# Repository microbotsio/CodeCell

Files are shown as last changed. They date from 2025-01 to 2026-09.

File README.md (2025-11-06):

# CodeCell

CodeCell

## Overview

CodeCell is a family of tiny boards that help you miniaturize your DIY robots, wearables, and IoT projects with ease! Designed for makers, each CodeCell features an Arduino-compatible ESP32 microcontroller, onboard sensors, and smart power management - all programmable over a standard USB-C cable. The USB-C port also charges the LiPo battery that connects directly to the onboard connector.

All CodeCell modules are supported by the **CodeCell Arduino Library**, which provides simple, ready-to-use functions for light, proximity, motion, and power management.  

You can even connect your CodeCell to our companion **MicroLink App** to add wireless sliders, buttons, joysticks, real-time sensor data, and a live 20-character display - Perfect for debugging!

Each version of CodeCell shares the same compact 1.85 cm (C3/C6) or 2.25 cm (C6 Drive) form factor and includes:

- **USB-C Port** – for programming, serial communication, and battery charging.  
- **LiPo Connector** – works with the included cable and the optional 170 mAh 20C battery (1.25 mm pitch).  
- **BQ24232 Power Management** – enables dynamic power-path control for simultaneous operation and charging.  
- **Programmable GPIO/PWM/ADC/I2C Pins** – expand your project with additional sensors, displays, or actuators.
- **CodeCell Library Support** – easy Arduino functions for reading sensors, LEDs, PWM, and sleep triggers.  
- **MicroLink App Integration** – wireless control and real-time feedback from your phone.
- **Sensors** – includes a **VCNL4040 light/proximity sensor** and the C3/C6/C6-Drive also include a **BNO085 9-axis IMU motion sensor** with onboard sensor-fusion algorithms for advanced orientation, motion, and activity detection.  

Available Versions:

| Model | Microcontroller | Features | Typical Use |
|:---|:---|:---|:---|
| **CodeCell C3 Light** | ESP32-C3-MINI-1-N4 | 4MB Flash, Wi-Fi 4 + BLE 5, LiPo Charging via USB-C, Light + Proximity Sensor | Basic sensing and IoT projects |
| **CodeCell C3** | ESP32-C3-MINI-1-N4 | 4MB Flash, Wi-Fi 4 + BLE 5, LiPo Charging via USB-C, Light + Proximity Sensor + 9-Axis IMU Motion Sensor | Robotics & Wearables |
| **CodeCell C6** | ESP32-C6-MINI-1-H8 | 8MB Flash, Wi-Fi 6 + BLE 5 + Zigbee, LiPo Charging via USB-C, Light + Proximity + 9-Axis IMU Sensor | Robotics & Wearables with Low-Power Modes |
| **CodeCell C6 Drive** | ESP32-C6-MINI-1-H8 | 8MB Flash, Wi-Fi 6 + BLE 5 + Zigbee, LiPo Charging via USB-C, Light + Proximity + 9-Axis IMU Sensor, Dual H-Bridge Motor Drivers | All-in-One Robotics Controller |

### 📦 Included in Every Box
- CodeCell module (C3 Light / C3 / C6 / C6 Drive)  
- Four M1.2 screws  
- Female headers (optional soldering)  
- 1.25 mm battery cable  
- Optional 170 mAh LiPo battery (add-on)

---

## Getting Started with the CodeCell Library

Get started and explore tutorials [here](https://microbots.io/pages/learn-codecell).

### 🧰 Arduino IDE Setup

Make sure the ESP32 boards package is installed  
(*Boards Manager → search for "esp32" by Espressif*).

#### For CodeCell C3 (ESP32-C3)
- Board: ESP32C3 Dev Module  
- USB CDC On Boot: Enabled        // Required for Serial over USB  
- CPU Frequency: 160 MHz  
- Flash Size: 4 MB (32 Mb)  
- Partition Scheme: Minimal SPIFFS (1.9MB APP with OTA / 190KB SPIFFS)  
- Port: Select the COM port for your CodeCell C3

#### For CodeCell C6 (ESP32-C6)
- Board: ESP32C6 Dev Module  
- USB CDC On Boot: Enabled        // Required for Serial over USB  
- CPU Frequency: 160 MHz  
- Flash Size: 8 MB (64 Mb)  
- Partition Scheme: 8M with SPIFFS (3 MB APP / 1.5 MB SPIFFS)  
- Port: Select the COM port for your CodeCell C6

### ⚙️ Init()

To initialize the CodeCell, use the `myCodeCell.Init()` function with one or more predefined macros.  
Each macro corresponds to a specific sensing function.

#### Available Macros
- LIGHT                          // Light + proximity sensing  
- MOTION_ACCELEROMETER           // 3-axis acceleration  
- MOTION_GYRO                    // 3-axis angular velocity  
- MOTION_MAGNETOMETER            // 3-axis magnetic field  
- MOTION_LINEAR_ACC              // Linear acceleration  
- MOTION_GRAVITY                 // Gravity vector  
- MOTION_ROTATION                // Roll, pitch, yaw (with mag)  
- MOTION_ROTATION_NO_MAG         // Roll, pitch, yaw (no mag)  
- MOTION_STEP_COUNTER            // Step count  
- MOTION_STATE                   // On table / Stationary / Stable / In motion  
- MOTION_TAP_DETECTOR            // Tap detection  
- MOTION_ACTIVITY                // Activity classification  

#### Example Usage
- myCodeCell.Init(LIGHT);                                 // Light only  
- myCodeCell.Init(LIGHT + MOTION_ROTATION);               // Light + orientation  
- myCodeCell.Init(LIGHT + MOTION_ROTATION + MOTION_STATE);// Light + orientation + state  

🧠 Combine multiple macros using the `+` operator to enable multiple sensors.

### 🔁 Run()

The `myCodeCell.Run()` function reads sensor data at a defined frequency and manages power and LED status.

#### Example
if (myCodeCell.Run(10)) {
  // Executes code every 10 Hz (every 100 ms)
}

- `myCodeCell.Run(10)` → returns `true` at 10 Hz (every 100 ms)  
- Read all enabled sensors at this rate  (Range: 1Hz - 100Hz)
- Also handles the LED power indicator and power status 

**Low battery behavior:**  
- Below ~3.3 V → LED blinks red ×10 → enters sleep until USB is reconnected  
- On USB → continues running loop(); LED shows charging/charged status  

### 🔋 Power & Battery Functions

#### PowerStateRead()
uint8_t state = myCodeCell.PowerStateRead();

Return values:
- 0 = Running from LiPo Battery  
- 1 = Running from USB Power  
- 2 = Power Initializing  
- 3 = Battery Low  
- 4 = Battery Fully Charged  
- 5 = Battery Charging  

#### BatteryVoltageRead()
int mv = myCodeCell.BatteryVoltageRead();   // e.g. 3720 (mV)  
Returns the LiPo voltage in millivolts — great for thresholds or logging.

#### BatteryLevelRead()
uint16_t lvl = myCodeCell.BatteryLevelRead();

Return values:
- 1–100  = Approximate battery percentage  
- 101    = Charging (USB connected, charging)  
- 102    = USB Power (bypassing battery)  

Example:
if (lvl <= 100) { Serial.println("Battery: " + String(lvl) + "%"); }  
else if (lvl == 101) { Serial.println("Charging..."); }  
else if (lvl == 102) { Serial.println("USB Power"); }  

### 📈 Reading Sensors

After initialization, you can read the sensors using these functions:

- Light_ProximityRead()                                           // Proximity  
- Light_WhiteRead()                                               // White light intensity  
- Light_AmbientRead()                                             // Ambient light  
- Motion_TapRead()                                                // Tap detection (1 = tap, 0 = none)  
- Motion_StepCounterRead()                                        // Step count  
- Motion_StateRead()                                              // On Table=1, Stationary=2, Stable=3, Motion=4  
- Motion_ActivityRead()                                           // Driving=1, Cycling=2, Walking=3/6, Still=4, Tilting=5, Running=7, Climbing=8  
- Motion_AccelerometerRead(float &x, float &y, float &z)          // Accelerometer (m/s²)  
- Motion_GyroRead(float &x, float &y, float &z)                   // Gyroscope (°/s)  
- Motion_MagnetometerRead(float &x, float &y, float &z)           // Magnetometer (µT)  
- Motion_GravityRead(float &x, float &y, float &z)                // Gravity vector  
- Motion_LinearAccRead(float &x, float &y, float &z)              // Linear acceleration  
- Motion_RotationRead(float &roll, float &pitch, float &yaw)      // Rotation (degrees)  
- Motion_RotationNoMagRead(float &roll, float &pitch, float &yaw) // Rotation w/o mag  
- Motion_RotationVectorRead(float &vec_r, float &vec_i, float &vec_j, float &vec_k) // Quaternion  

#### Example Usage
- uint16_t proximity = myCodeCell.Light_ProximityRead();  
- myCodeCell.Motion_AccelerometerRead(x, y, z);  
- myCodeCell.Motion_RotationRead(roll, pitch, yaw);  

🧠 Tip: Use `myCodeCell.PrintSensors();` to print all enabled sensor readings to the Serial Monitor.

### ⚡ GPIO Control
- myCodeCell.pinWrite(uint8_t pin, bool value);              // Digital write  
- myCodeCell.pinRead(uint8_t pin);                           // Digital read  
- myCodeCell.pinPWM(uint8_t pin, uint16_t freq, uint8_t dc); // PWM output (Hz, duty%)  
- myCodeCell.pinADC(uint8_t pin);                            // Analog read  

### 💡 Onboard LED Control
- myCodeCell.LED_SetBrightness(0);   // Turn off CodeCell LED  
- myCodeCell.LED_SetBrightness(10);  // Full brightness  

### 💤 Sleep Functions
- myCodeCell.SleepTimer(uint16_t sleep_sec);  
- myCodeCell.SleepProximityTrigger(uint16_t threshold);  // C6 only  
- myCodeCell.SleepLightTrigger(uint16_t threshold);      // C6 only  
- myCodeCell.SleepDarkTrigger(uint16_t threshold);       // C6 only  
- myCodeCell.SleepTapTrigger();                          // C6 only  

### 📱 MicroLink App Integration
- Download the MicroLink library to connect the CodeCell with the companion smartphone app.  
- Enables wireless sensor reading, joystick control, buttons and sliders.  

---

## Attribution
This 'CodeCell' library contains various features, including device intialization, power managment, light sensning and motion sensing. The VCNL4040 light sensor code does not rely on any external libraries. But some of the BNO085 Motion-sensor functions were adapted from the [SparkFun BNO08x Arduino Library](https://github.com/sparkfun/SparkFun_BNO08x_Arduino_Library) and the official library provided by [CEVA](https://github.com/ceva-dsp/sh2/tree/main) for the SH2 sensor hub.

The SparkFun BNO08x library, originally written by Nathan Seidle and adjusted by Pete Lewis at SparkFun Electronics, is released under the MIT License. Significant modifications were made to adapt it and integrate into the 'CodeCell' library.

Additionally, this project incorporates the official [CEVA SH2 sensor hub library files](https://github.com/ceva-dsp/sh2/tree/main), which is licensed under the [Apache License 2.0](http://www.apache.org/licenses/LICENSE-2.0).

CEVA’s notice is as follows:

This software is licensed from CEVA, Inc.  
Copyright (c) CEVA, Inc. and its licensors. All rights reserved.  
CEVA and the CEVA logo are trademarks of CEVA, Inc.  
For more information, visit [CEVA's website](https://www.ceva-dsp.com/app/motion-sensing/).

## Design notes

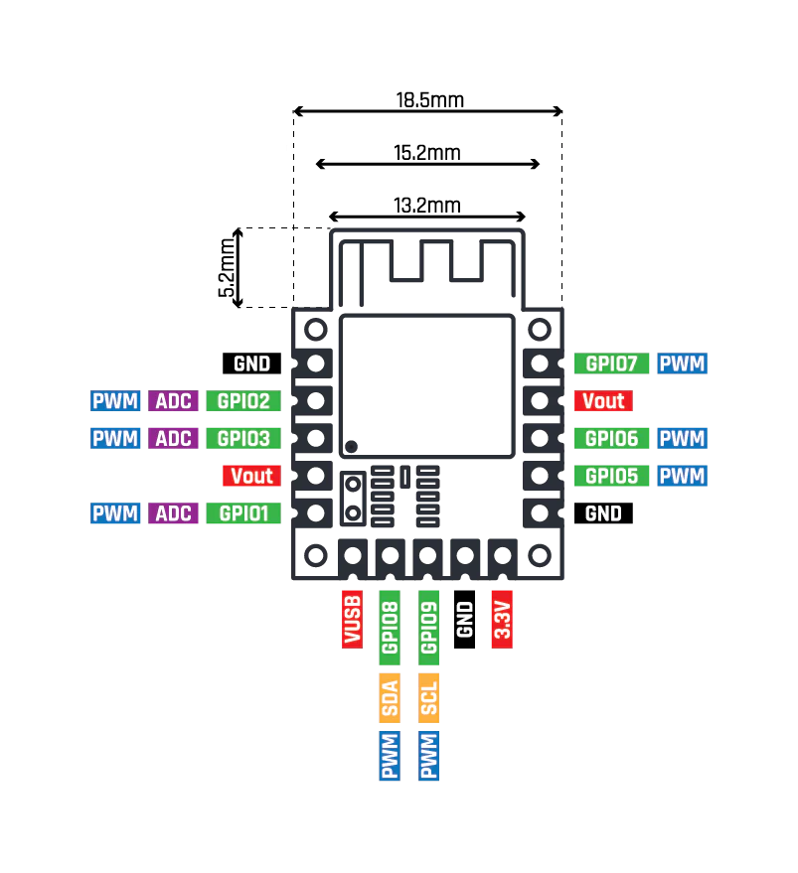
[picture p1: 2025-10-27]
hardware/CodeCell C3 Light/CodeCell C3 Light Pin Map.png

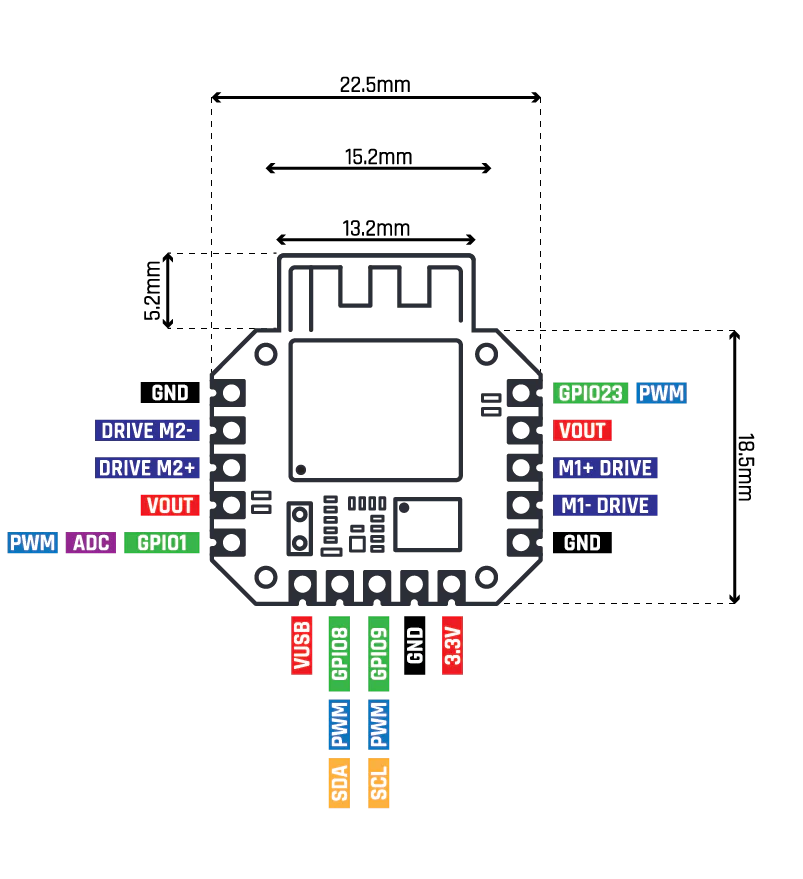
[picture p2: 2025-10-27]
hardware/CodeCell C6 Drive/CodeCell C6 Drive Pin Map.png

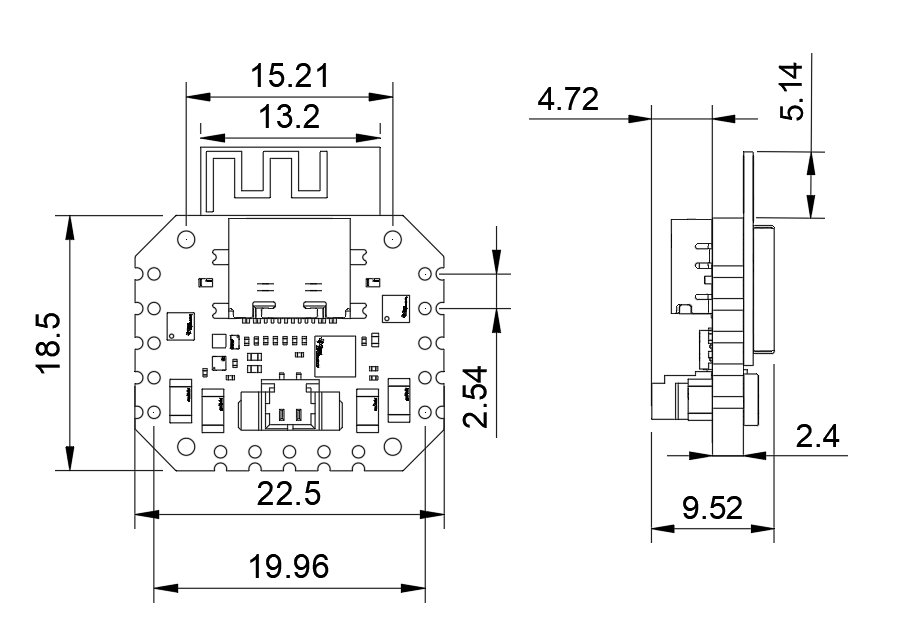
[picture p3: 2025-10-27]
hardware/CodeCell C6 Drive/CodeCell C6 Drive Drawing.png

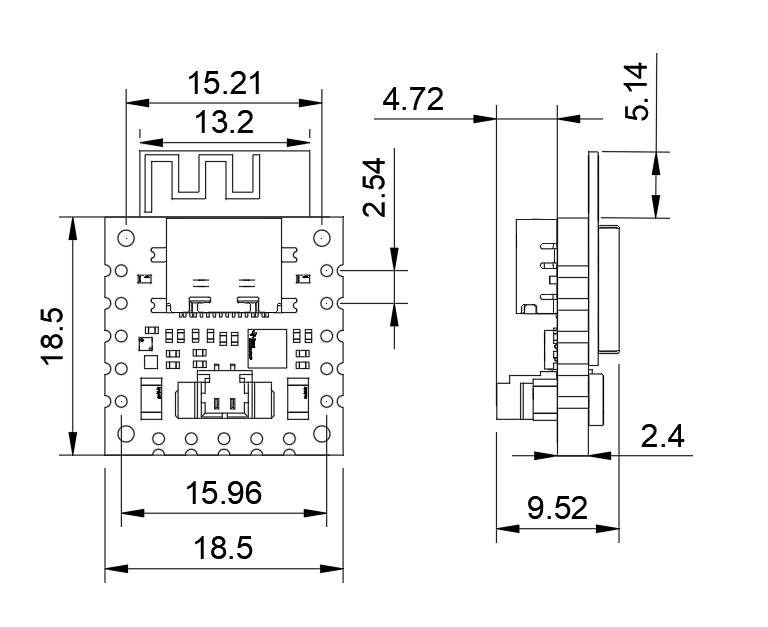
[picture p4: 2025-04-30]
hardware/CodeCell C3/codecell drawing.png

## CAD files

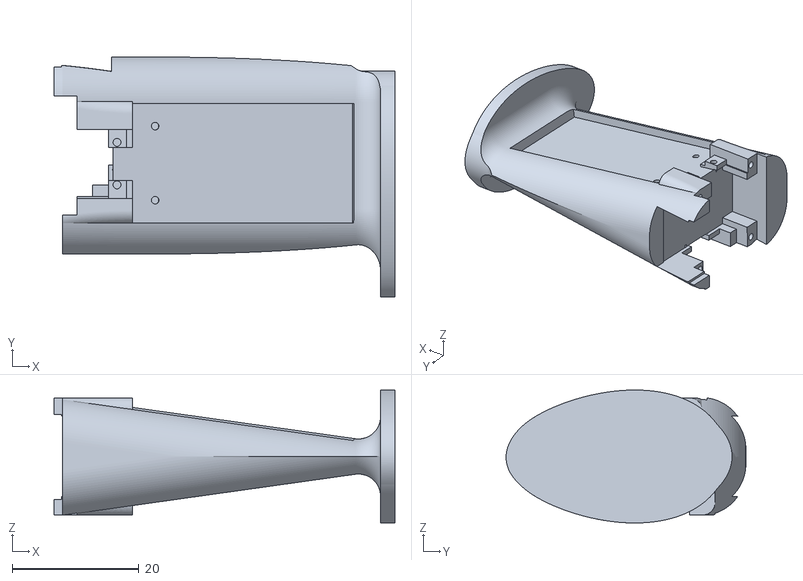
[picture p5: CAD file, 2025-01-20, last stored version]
hardware/Projects/Flappy Bot/FlappyBot_Holder.stl
53.9 x 37.9 x 21.0

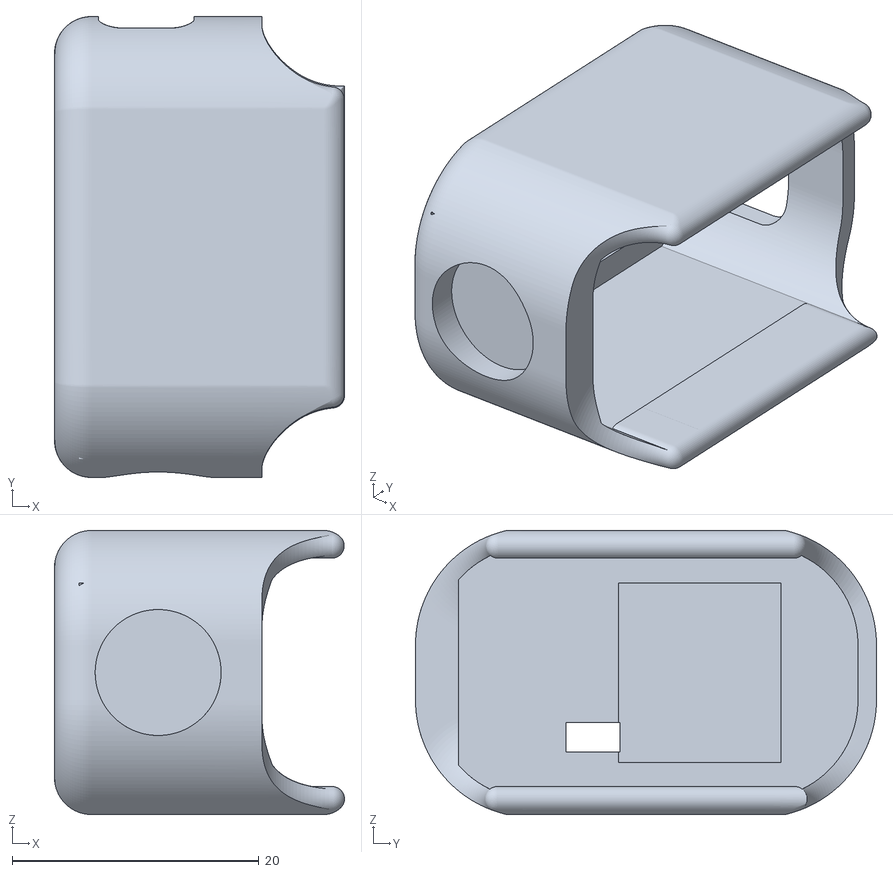
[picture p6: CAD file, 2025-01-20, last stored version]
hardware/Projects/Flappy Bot/FlappyBot_Head.stl
23.5 x 37.3 x 23.0

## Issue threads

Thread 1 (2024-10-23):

Sensor init issue

quinm0, 2024-10-23:
Hi, I plan on looking into this more myself but I just want to document the first issue I got

I was using the example from the library

```
#include <CodeCell.h>

CodeCell myCodeCell;

/*
 * Overview:
 * This code shows you how easy it is to set up and run the CodeCell. You just needs to specify which sensors to enable by
 * passing the appropriate macros to the `Init()` function and use the `Run()` function to handle the power and battery management.
 *
 **** Initialization (`Init` function):
 *
 * To initialize the CodeCell, use the `myCodeCell.Init()` function with one or more of the predefined macros. Each macro
 * corresponds to a specific sensing function. Here are the available macros:
 *
 * - `LIGHT`                          // Enables Light Sensing
 * - `MOTION_ACCELEROMETER`           // Enables Accelerometer Sensing
 * - `MOTION_GYRO`                    // Enables Gyroscope Sensing
 * - `MOTION_MAGNETOMETER`            // Enables Magnetometer Sensing
 * - `MOTION_LINEAR_ACC`              // Enables Linear Acceleration Sensing
 * - `MOTION_GRAVITY`                 // Enables Gravity Sensing
 * - `MOTION_ROTATION`                // Enables Rotation Sensing
 * - `MOTION_ROTATION_NO_MAG`         // Enables Rotation Sensing without Magnetometer
 * - `MOTION_STEP_COUNTER`            // Enables Walking Step Counter
 * - `MOTION_STATE`                   // Enables Motion State Detection
 * - `MOTION_TAP_DETECTOR`            // Enables Tap Detector
 * - `MOTION_ACTIVITY`                // Enables Motion Activity Recognition
 *
 * Example Usage:
 * - `myCodeCell.Init(LIGHT);`                                      // Initializes Light Sensing
 * - `myCodeCell.Init(LIGHT + MOTION_ROTATION);`                    // Initializes Light Sensing and Angular Rotation Sensing
 * - `myCodeCell.Init(LIGHT + MOTION_ROTATION + MOTION_STATE);`     // Initializes Light Sensing, Angular Rotation Sensing, and State Detection
 *
 * Note: You can combine multiple macros using the `+` operator to initialize multiple sensors.
 *
 **** Running the Code (`Run` function):
 *
 * Call the `myCodeCell.Run()` function in the `loop()` to manage battery and power. This function returns true every 100ms and
 * also handles the onboard LED to indicate power status. When the battery voltage falls below 3.3V, the LED will blink red 10 times
 * and then go into Sleep Mode until the USB cable is connected for charging. While charging, the CodeCell will shut down the application,
 * light the LED blue, and wait until the battery is fully charged. Once fully charged, it will start a breathing-light animation with a speed
 * corresponding to the proximity distance. The LED will shine green when powered by the battery and blue when powered via USB.
 *
 **** Reading Sensor Data:
 *
 * After initializing the sensors, you can use the following functions to read data from them:
 *
 * Sensor Read Functions:
 *
 * - `Light_ProximityRead()`                                            // Reads the proximity value from the light sensor
 * - `Light_WhiteRead()`                                                // Reads the white light intensity from the light sensor
 * - `Light_AmbientRead()`                                              // Reads the ambient light intensity from the light sensor
 * - `Motion_TapRead()`                                                  // Reads the number of taps detected (tap = 1, no tap = 0)
 * - `Motion_StateRead()`                                               // Reads the current state (On Table = 1, Stationary = 2, Stable = 3, Motion = 4)
 * - `Motion_ActivityRead()`                                            // Reads the current activity (Driving = 1, Cycling = 2, Walking = 3/6, Still = 4, Tilting = 5, Running = 7, Climbing Stairs = 8)
 * - `Motion_AccelerometerRead(float &x, float &y, float &z)`           // Reads acceleration data along the x, y, and z axes
 * - `Motion_GyroRead(float &x, float &y, float &z)`                    // Reads rotational velocity data along the x, y, and z axes
 * - `Motion_MagnetometerRead(float &x, float &y, float &z)`            // Reads magnetic field strength data along the x, y, and z axes
 * - `Motion_GravityRead(float &x, float &y, float &z)`                 // Reads gravity vector data along the x, y, and z axes
 * - `Motion_LinearAccRead(float &x, float &y, float &z)`               // Reads linear acceleration data along the x, y, and z axes
 * - `Motion_StepCounterRead(uint16_t &x)`                              // Reads the number of steps counted
 * - `Motion_RotationRead(float &roll, float &pitch, float &yaw)`       // Reads angular rotational data (roll, pitch, yaw)
 * - `Motion_RotationNoMagRead(float &roll, float &pitch, float &yaw)`  // Reads angular rotational data without magnetometer
 *
 * Example Usage:
 * - `uint16_t proximity = myCodeCell.Light_ProximityRead();`
 * - `myCodeCell.Motion_AccelerometerRead(myX, myY, myZ);`
 * - `myCodeCell.Motion_RotationRead(myRoll, myPitch, myYaw);`
 *
 * Note: You can use `myCodeCell.PrintSensors()`to prints the values of all enabled sensors on the Serial Monitor.
 *
 */

void setup() {
  Serial.begin(115200); /* Set Serial baud rate to 115200. Ensure Tools/USB_CDC_On_Boot is enabled if using Serial. */

  myCodeCell.Init(LIGHT); /*Initializes Light Sensing*/
}

void loop() {
  if (myCodeCell.Run()) {
    /*Runs  every 100ms - Put your code here*/
    myCodeCell.PrintSensors(); /*Print Sensors data every 100ms*/
  }
}

```

And following
```
 * Example Usage:
 * - `myCodeCell.Init(LIGHT);`                                      // Initializes Light Sensing
 * - `myCodeCell.Init(LIGHT + MOTION_ROTATION);`                    // Initializes Light Sensing and Angular Rotation Sensing
 * - `myCodeCell.Init(LIGHT + MOTION_ROTATION + MOTION_STATE);`     // Initializes Light Sensing, Angular Rotation Sensing, and State Detection
```

I added `+ MOTION_ACCELEROMETER` to the example init call.

And I get the following.
Note, the default example works just fine, just adding the `+ MOTION_ACCELEROMETER` causes the issue
```
ESP-ROM:esp32c3-api1-20210207
Build:Feb  7 2021
rst:0x3 (RTC_SW_SYS_RST),boot:0xe (SPI_FAST_FLASH_BOOT)
Saved PC:0x40048b82
SPIWP:0xee
mode:DIO, clock div:1
load:0x3fcd5820,len:0x1058
load:0x403cc710,len:0x8a8
load:0x403ce710,len:0x2fac
entry 0x403cc710

Hello World! I am your CodeCell
Please wait while I setup my sensors.. Light Sensing Enabled + Guru Meditation Error: Core  0 panic'ed (Load access fault). Exception was unhandled.

Core  0 register dump:
MEPC    : 0x4200199c  RA      : 0x4200093c  SP      : 0x3fc990d0  GP      : 0x3fc8ea00
TP      : 0x3fc89bf4  T0      : 0x00000000  T1      : 0x403887e8  T2      : 0x61656c50
S0/FP   : 0x3fc8f720  S1      : 0x3fc90000  A0      : 0x00000000  A1      : 0x00000000
A2      : 0x3fc990df  A3      : 0x00000001  A4      : 0x600c0000  A5      : 0x3fc8f768
A6      : 0x3fc9901c  A7      : 0x3fc99020  S2      : 0x00000065  S3      : 0x3fc90000
S4      : 0x00000000  S5      : 0x00000000  S6      : 0x00000000  S7      : 0x00000000
S8      : 0x00000000  S9      : 0x00000000  S10     : 0x00000000  S11     : 0x00000000
T3      : 0x00000094  T4      : 0x00000800  T5      : 0x00000006  T6      : 0x00000000
MSTATUS : 0x00001881  MTVEC   : 0x40380001  MCAUSE  : 0x00000005  MTVAL   : 0x00000014
MHARTID : 0x00000000

Stack memory:
3fc990d0: 0x00000000 0x00000000 0x00000000 0x01000000 0x00000094 0x00000800 0x00000006 0x42001d9c
3fc990f0: 0x00000033 0x3fc90000 0x3fc8f720 0x420036c8 0x00000000 0x00000000 0x00000000 0x00000000
3fc99110: 0x00000033 0x3fc90000 0x3fc8f720 0x420037ca 0x00000000 0x00000000 0x00000000 0x420074de
3fc99130: 0x00000000 0x00000000 0x00000000 0x40389ac8 0x00000000 0x00000000 0x00000000 0x00000000
3fc99150: 0x00000000 0x00000000 0x00000000 0x00000000 0x00000000 0xa5a5a5a5 0xa5a5a5a5 0xa5a5a5a5
3fc99170: 0xa5a5a5a5 0xa5a5a5a5 0xbaad5678 0x00000160 0xabba1234 0x00000154 0x3fc99070 0x00000523
3fc99190: 0x3fc90970 0x3fc90970 0x3fc99188 0x3fc90968 0x00000018 0x3fc94908 0x3fc94908 0x3fc99188
3fc991b0: 0x00000000 0x00000001 0x3fc97178 0x706f6f6c 0x6b736154 0x3fc99400 0x00c99658 0x00000000
3fc991d0: 0x3fc99170 0x00000001 0x00000000 0x00000000 0x00000000 0x00000000 0x3fc92780 0x3fc927e8
3fc991f0: 0x3fc92850 0x00000000 0x00000000 0x00000001 0x00000000 0x00000000 0x00000000 0x42024f16
3fc99210: 0x00000000 0x00000000 0x00000000 0x00000000 0x00000000 0x00000000 0x00000000 0x00000000
3fc99230: 0x00000000 0x00000000 0x00000000 0x00000000 0x00000000 0x00000000 0x00000000 0x00000000
3fc99250: 0x00000000 0x00000000 0x00000000 0x00000000 0x00000000 0x00000000 0x00000000 0x00000000
3fc99270: 0x00000000 0x00000000 0x00000000 0x00000000 0x00000000 0x00000000 0x00000000 0x00000000
3fc99290: 0x00000000 0x00000000 0x00000000 0x00000000 0x00000000 0x00000000 0x00000000 0x00000000
3fc992b0: 0x00000000 0x00000000 0x00000000 0x00000000 0x00000000 0x00000000 0x00000000 0x00000000
3fc992d0: 0x00000000 0x00000000 0xb2000000 0xbaad5678 0x00000060 0xabba1234 0x00000054 0x00000000
3fc992f0: 0x3fc992ec 0x00000000 0x00000000 0x00000000 0x3fc99304 0xffffffff 0x3fc99304 0x3fc99304
3fc99310: 0x00000000 0x3fc99318 0xffffffff 0x3fc99318 0x3fc99318 0x00000001 0x00000001 0x00000000
3fc99330: 0xab00ffff 0x00000000 0xb33fffff 0x00000000 0xbaad5678 0x00000160 0xabba1234 0x00000154
3fc99350: 0x3fc993a4 0x3fc993a4 0x3fc994a4 0x3fc994a3 0x00000000 0x3fc99368 0xffffffff 0x3fc99368
3fc99370: 0x3fc99368 0x00000000 0x3fc9937c 0xffffffff 0x3fc9937c 0x3fc9937c 0x00000000 0x00000100
3fc99390: 0x00000001 0x3f00ffff 0x00000000 0xb33fffff 0x00000000 0x6d207075 0x65732079 0x726f736e
3fc993b0: 0x202e2e73 0x776f6e69 0x2e2e7265 0x72500a0a 0x6d69786f 0xad427469 0x20c93ae3 0x35e6014e
3fc993d0: 0xfde87a79 0x768916f2 0x7ded35f9 0x6364ab25 0x0188fd72 0x1c710fc8 0xc320b46d 0x1b200100
3fc993f0: 0xf0eafe6b 0xefafb3b7 0xbf2bbeff 0xd3fd75f9 0x687c063f 0x74fc789e 0xc4084012 0xed19a836
3fc99410: 0x6d33cb13 0x5abbf116 0xdfca3dfe 0x81094d4e 0x3fcb1b03 0x965e8a10 0xd59d8973 0x822f7e6d
3fc99430: 0xbdffa339 0x6fdff7f1 0x7bf7f32f 0x667fafad 0x24330707 0x48470868 0xa2b53d35 0x44a9c44c
3fc99450: 0x9f7ffff5 0xf9dbaf16 0x37d7d311 0xff4ff312 0x2d2e7563 0x750209c5 0x31803043 0x5a433f00
3fc99470: 0xf71d97b0 0xfc3a6e2e 0xbffde733 0xa3b10b7e 0x25a08220 0x2bc80a72 0x4b08094c 0xa24010ba
3fc99490: 0xf6b7ec90 0x9f71bfc0 0x512e72fe 0xd1771fa7 0x832628d0 0xbaad5678 0x0000007c 0xabba1234
3fc994b0: 0x00000070 0x00000100 0x00000100 0x00000002 0x40385b0c 0x4038618c 0x40385a42 0x403866d4

ELF file SHA256: 1135b25dfb9d017e

Rebooting...
ESP-ROM:esp32c3-api1-20210207
Build:Feb  7 2021
rst:0x3 (RTC_SW_SYS_RST),boot:0xe (SPI_FAST_FLASH_BOOT)
Saved PC:0x40048b82
SPIWP:0xee
mode:DIO, clock div:1
load:0x3fcd5820,len:0x1058
load:0x403cc710,len:0x8a8
load:0x403ce710,len:0x2fac
entry 0x403cc710

```

microbotsio, 2024-10-24:
Hi Quin

Thanks for reaching out and for your recent order. From your order number I
can see that you ordered the Light sensor not the Light + Motion sensor

This means that the CodeCell is not finding the motion sensor when you
added "+ MOTION_ACCELEROMETER", as it is not present on the board -so it
keeps resetting indicating the error

Let me know if you have further questions.

[image: Logo]
Microbots Team
Miniaturized Robotics + Simplified Electronics
email: ***@***.***
www.microbots.io
[image: Twitter icon] <https://twitter.com/microbots_io>  [image: Instagram
icon] <https://www.instagram.com/microbots.io/>

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

microbotsio, 2024-10-24:
Hi Quin

Are you using the CodeCell Light or CodeCell light+motion?

This means that the CodeCell is not finding the motion sensor when you
added "+ MOTION_ACCELEROMETER", as it is not present on the board -so it
keeps resetting indicating the error

Let me know if you have further questions.

Closed 2025-02-08.

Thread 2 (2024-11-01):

Turn off superbright green led

divbell, 2024-11-01:
When I'm running this on a battery, there's an eye-melting green led saturating my visual cortex. :)

How does one turn off this led?  Apologies if this is super basic.

microbotsio, 2024-11-05:
Thanks for your feedback! The led is automatically run to indicate the battery status in the Run() function. We will limit it brightness in the next release

microbotsio, 2025-02-08:
Updated on v1.2.4

Closed 2025-02-08.

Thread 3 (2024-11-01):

When connected to USB with battery connected, application does not run

divbell, 2024-11-01:
I've noticed that when I have the battery connected and the USB connected, the application shuts down and it goes into battery charging mode and never seems to return to the application, even when the battery is apparently charged (or charged enough).

Is there a way to keep the application running while connected to USB with a battery connected, and use excess power to top-off the battery?

microbotsio, 2024-11-05:
This can be done, however the Run function currently put the device in sleep mode while the battery is connected and charging via usb, turning off all gpio pins. We will consider adding a way to disable this in the next release

greiginsydney, 2025-01-31:
> We will consider adding a way to disable this in the next release

That would be helpful, as it would allow us to debug via the USB/serial port

microbotsio, 2025-02-25:
Just released a new software release v1.2.7 that introduced the USBChargeState() function to optional keep CodeCell awake while charging. Here's how you can use it in the setup:

`void setup() {
  Serial.begin(115200); // Set Serial baud rate to 115200 - Ensure Tools/USB_CDC_On_Boot is enabled if using Serial

  myCodeCell.Init(LIGHT); // Initializes Light Sensor

  myCodeCell.USBChargeState(1);
}`

Please note when enabling this option the battery will automatically keep charging and the LED will blink blue to indicate the USB power

Closed 2025-02-25.

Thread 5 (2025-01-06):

Change run() send frequency

mhl787156, 2025-01-06:
Hi guys,

I noticed that your run() function seems to default to 10hz - is it possible to change this and speed it up to > 50hz?

microbotsio, 2025-01-09:
Hi Mickey

We will include this feature in the next version, enabling you to adjust
the speed of the run function.

Additionally, if you'd like, you can place code outside the run() function
to execute it more quickly, while keeping only the code inside the run()
function that needs to operate at 10Hz.

-Team Microbots

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

microbotsio, 2025-02-08:
Updated on v1.2.4

myCodeCell.Run(50) every 50Hz

Closed 2025-02-08.

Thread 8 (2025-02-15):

Interrupt connected?

braddo99, 2025-02-15:
Hey, the schematic shows the BNO085 interrupt pin is not connected, is that true?

I'm trying to use the CodeCell in an application that seems to require/use the interrupt for the BNO085, it would be great if that is a mistake and it actually is connected :-)

Thanks, cool product!

microbotsio, 2025-02-15:
Unfortunately the interrupt pin was not feasible to include it, as we ran
out of pins. However you can poll the sensor and even go to sleep, like
shown in this example:
https://github.com/microbotsio/CodeCell/blob/main/examples/Light_SleepExample/Light_SleepExample.ino

Let us know if you have any further questions

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

braddo99, 2025-02-15:
Thanks for the reply. Sorry for a couple more questions on this topic because I don't control the software for the project and if i can't hook up the interrupt I can't use your boards, and I now own 4 :-(
Is there any place on the board where the int pin for the BNO physically exists (other than under the chip pad) so that I might jumper it to an open gpio?
The Arduino IDE does work and I have run some of your examples, great! But, I haven't been able to upload the code to the board at all yet using VS Code and Platformio. Do you have any instructions for that?
Thanks again,
Brad

    On Saturday, February 15, 2025 at 02:35:25 AM EST, microbots ***@***.***> wrote:

  Unfortunately the interrupt pin was not feasible to include it, as we ran<br>out of pins. However you can poll the sensor and even go to sleep, like<br>shown in this example:<br>https://github.com/microbotsio/CodeCell/blob/main/examples/Light_SleepExample/Light_SleepExample.ino<br><br>Let us know if you have any further questions<br><br><br>On Sat, 15 Feb 2025 at 05:01, braddo99 ***@***.***&gt; wrote:<br><br>&gt; Hey, the schematic shows the BNO085 interrupt pin is not connected, is<br>&gt; that true?<br>&gt;<br>&gt; I&#39;m trying to use the CodeCell in an application that seems to require/use<br>&gt; the interrupt for the BNO085, it would be great if that is a mistake and it<br>&gt; actually is connected :-)<br>&gt;<br>&gt; Thanks, cool product!<br>&gt;<br>&gt; —<br>&gt; Reply to this email directly, view it on GitHub<br>&gt; &lt;https://github.com/microbotsio/CodeCell/issues/8&gt;, or unsubscribe<br>&gt; &lt;https://github.com/notifications/unsubscribe-auth/BIOADCRFCFOPX5PA3WY4IID2P232RAVCNFSM6AAAAABXF4N5IGVHI2DSMVQWIX3LMV43ASLTON2WKOZSHA2TKMJQGEYDQNI&gt;<br>&gt; .<br>&gt; You are receiving this because you are subscribed to this thread.Message<br>&gt; ID: ***@***.***&gt;<br>&gt; [image: braddo99]*braddo99* created an issue (microbotsio/CodeCell#8)<br>&gt; &lt;https://github.com/microbotsio/CodeCell/issues/8&gt;<br>&gt;<br>&gt; Hey, the schematic shows the BNO085 interrupt pin is not connected, is<br>&gt; that true?<br>&gt;<br>&gt; I&#39;m trying to use the CodeCell in an application that seems to require/use<br>&gt; the interrupt for the BNO085, it would be great if that is a mistake and it<br>&gt; actually is connected :-)<br>&gt;<br>&gt; Thanks, cool product!<br>&gt;<br>&gt; —<br>&gt; Reply to this email directly, view it on GitHub<br>&gt; &lt;https://github.com/microbotsio/CodeCell/issues/8&gt;, or unsubscribe<br>&gt; &lt;https://github.com/notifications/unsubscribe-auth/BIOADCRFCFOPX5PA3WY4IID2P232RAVCNFSM6AAAAABXF4N5IGVHI2DSMVQWIX3LMV43ASLTON2WKOZSHA2TKMJQGEYDQNI&gt;<br>&gt; .<br>&gt; You are receiving this because you are subscribed to this thread.Message<br>&gt; ID: ***@***.***&gt;<br>&gt;<br>
—
Reply to this email directly, view it on GitHub, or unsubscribe.
You are receiving this because you authored the thread.Message ID: ***@***.***>
microbotsio left a comment (microbotsio/CodeCell#8) Unfortunately the interrupt pin was not feasible to include it, as we ran<br>out of pins. However you can poll the sensor and even go to sleep, like<br>shown in this example:<br>https://github.com/microbotsio/CodeCell/blob/main/examples/Light_SleepExample/Light_SleepExample.ino<br><br>Let us know if you have any further questions<br><br><br>On Sat, 15 Feb 2025 at 05:01, braddo99 ***@***.***&gt; wrote:<br><br>&gt; Hey, the schematic shows the BNO085 interrupt pin is not connected, is<br>&gt; that true?<br>&gt;<br>&gt; I&#39;m trying to use the CodeCell in an application that seems to require/use<br>&gt; the interrupt for the BNO085, it would be great if that is a mistake and it<br>&gt; actually is connected :-)<br>&gt;<br>&gt; Thanks, cool product!<br>&gt;<br>&gt; —<br>&gt; Reply to this email directly, view it on GitHub<br>&gt; &lt;https://github.com/microbotsio/CodeCell/issues/8&gt;, or unsubscribe<br>&gt; &lt;https://github.com/notifications/unsubscribe-auth/BIOADCRFCFOPX5PA3WY4IID2P232RAVCNFSM6AAAAABXF4N5IGVHI2DSMVQWIX3LMV43ASLTON2WKOZSHA2TKMJQGEYDQNI&gt;<br>&gt; .<br>&gt; You are receiving this because you are subscribed to this thread.Message<br>&gt; ID: ***@***.***&gt;<br>&gt; [image: braddo99]*braddo99* created an issue (microbotsio/CodeCell#8)<br>&gt; &lt;https://github.com/microbotsio/CodeCell/issues/8&gt;<br>&gt;<br>&gt; Hey, the schematic shows the BNO085 interrupt pin is not connected, is<br>&gt; that true?<br>&gt;<br>&gt; I&#39;m trying to use the CodeCell in an application that seems to require/use<br>&gt; the interrupt for the BNO085, it would be great if that is a mistake and it<br>&gt; actually is connected :-)<br>&gt;<br>&gt; Thanks, cool product!<br>&gt;<br>&gt; —<br>&gt; Reply to this email directly, view it on GitHub<br>&gt; &lt;https://github.com/microbotsio/CodeCell/issues/8&gt;, or unsubscribe<br>&gt; &lt;https://github.com/notifications/unsubscribe-auth/BIOADCRFCFOPX5PA3WY4IID2P232RAVCNFSM6AAAAABXF4N5IGVHI2DSMVQWIX3LMV43ASLTON2WKOZSHA2TKMJQGEYDQNI&gt;<br>&gt; .<br>&gt; You are receiving this because you are subscribed to this thread.Message<br>&gt; ID: ***@***.***&gt;<br>&gt;<br>
—
Reply to this email directly, view it on GitHub, or unsubscribe.
You are receiving this because you authored the thread.Message ID: ***@***.***>

microbotsio, 2025-02-17:
Hi Brad We understand the frustration and appreciate your feedback :)

Unfortunately the interrupt pin could not be connected due to the small size of the module. So at the moment we suggest polling the sensor, but we are considering other solution for future versions of the board to make it more accessible.

You can use Platform IO for any esp32 device, including the CodeCell. But at the moment the library is not compatible because PlatrformIO does use the latest/same libraries for the esp32 board manger, as the Arduino IDE , so its fails to build and initialize the timers. So for now we suggest using the Arduino IDE to use the codecell library, but we will take note of your request and try to push it for later this year

braddo99, 2025-02-18:
I have to use VS Code and PltformIO because that is the platform the code I am using is built on. However, I could probably adjust the version of the esp32 libraries that are used etc. But I do think I require a board/configuration file for your device to take into account how the pins (even ones I"m not using) are connected. Do you have any information on that? It may be possible to tack a wire onto the pad for the interrupt, luckily how you have it oriented on the board makes it relatively accessible. Not easy since it's just a pad underneath, but I can see some exposed solder paste, maybe I can get a micro wire under there with the microscope. It would be great if you could connect the interrupt in a future version, I'm not sure about the size constraint - if you put a 0 ohm resistor on so that a user could switch out the light sensor or even just a pad so that one could solder to it, that would be useful. Maybe even set some fuses in the firmware that would allow a user to point IO to the desired devices on the board.
    On Monday, February 17, 2025 at 10:24:57 AM EST, microbots ***@***.***> wrote:

Hi Brad We understand the frustration and appreciate your feedback :)

Unfortunately the interrupt pin could not be connected due to the small size of the module. So at the moment we suggest polling the sensor, but we are considering other solution for future versions of the board to make it more accessible.

You can use Platform IO for any esp32 device, including the CodeCell. But at the moment the library is not compatible because PlatrformIO does use the latest/same libraries for the esp32 board manger, as the Arduino IDE , so its fails to build and initialize the timers. So for now we suggest using the Arduino IDE to use the codecell library, but we will take note of your request and try to push it for later this year

—
Reply to this email directly, view it on GitHub, or unsubscribe.
You are receiving this because you authored the thread.Message ID: ***@***.***>
microbotsio left a comment (microbotsio/CodeCell#8)
Hi Brad We understand the frustration and appreciate your feedback :)

Unfortunately the interrupt pin could not be connected due to the small size of the module. So at the moment we suggest polling the sensor, but we are considering other solution for future versions of the board to make it more accessible.

You can use Platform IO for any esp32 device, including the CodeCell. But at the moment the library is not compatible because PlatrformIO does use the latest/same libraries for the esp32 board manger, as the Arduino IDE , so its fails to build and initialize the timers. So for now we suggest using the Arduino IDE to use the codecell library, but we will take note of your request and try to push it for later this year

—
Reply to this email directly, view it on GitHub, or unsubscribe.
You are receiving this because you authored the thread.Message ID: ***@***.***>

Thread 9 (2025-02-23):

CodeCell restart Issues with Run() Function

JamesMegariotis, 2025-02-23:
Hi,

I just purchased a few codecells to test for an IOT sensor project we have been working on. I am really struggling to understand the logic behind some of the power state logic in the [Run()](https://github.com/microbotsio/CodeCell/blob/219996ab81475c8aa5fdf79adadb00b16f6efbb9/src/CodeCell.cpp#L379) function in CodeCell.cpp. I am experiencing random restarts when on battery power. I have had to implement my own helper functions and completely avoid using the codecell library. I am now wondering if there is a reason this logic is implemented this way.

It appears, as best I can understand the logic, is that the ESP32 is put to sleep via USBSleep() function when the battery is charging. Is there a design limitation that necessitates this behavior? Or is this just a matter of preference? I only ask since this seems like a power save function, but during charging, power consumption of the main program should not be much of a concern, so I am wondering if there is another motive behind this decision.

It also seems to issue esp_restart() ([line 445](https://github.com/microbotsio/CodeCell/blob/219996ab81475c8aa5fdf79adadb00b16f6efbb9/src/CodeCell.cpp#L445) and[ line 420](https://github.com/microbotsio/CodeCell/blob/219996ab81475c8aa5fdf79adadb00b16f6efbb9/src/CodeCell.cpp#L420)) when the TI charge controller IC is in the charge state. I am sure that these restarts appear to be called at times that are not appropriate based on my testing. The longest my code runs without a restart is 5 mins on battery power with nominal battery voltage and no USB plugged in. This appears to be a bug of some sort causing esp_restart() to be called even with the usb unplugged and a valid battery charge is present. Could this possibly be due to the [USB_VOLTAGE](https://github.com/microbotsio/CodeCell/blob/219996ab81475c8aa5fdf79adadb00b16f6efbb9/src/CodeCell.h#L16) threshold being set to 4.1V. I beleive the charger IC is charging to above that voltage? I am suspicious the issue lies in the following [lines of code](https://github.com/microbotsio/CodeCell/blob/219996ab81475c8aa5fdf79adadb00b16f6efbb9/src/CodeCell.cpp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) running erroneously and may be triggered by a high battery voltage.

I have a similar question for this feature. Is there a design reason behind this decision to restart the esp32 when a USB is plugged or unplugged?

Also any clarity you could provide on the [charge state constants](https://github.com/microbotsio/CodeCell/blob/219996ab81475c8aa5fdf79adadb00b16f6efbb9/src/CodeCell.h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) would be appreciated. I think I understand what some of these states represent, but not 100% sure on others, specifically POWER_INIT and POWER_BAT_CHRG_FULL. Do these represent USB power being applied and the completion of charging?

I would love to use this library as it simplifies the interface significantly, but it seems to be at odds with the purpose of our sensor firmware. Is it required to execute the run() function in the arduino loop? I initially thought it was, but now I am beginning to question that assumption.

Any insight you have on these questions as well as the unexpected reboot issue on battery power would be appreciated.

Thanks,
James

microbotsio, 2025-02-24:
Hi James

Thanks for reaching out :) Can you share your code in the
initialization and loop? And also verify that you are using the latest
library version?

Calling the Run() function in the main loop should not trigger any resets -
in software version v1.2.4 (and below) a soft reset was being called if a
sensor is read but not initialized, but in v1.2.5 this was updated,
outputting an error on the serial monitor instead. So it seems very
strange that the CodeCell is resetting itself.

Regarding the Power Handling, on v1.2.6 a soft reset is being applied in
the Run() function in the cases listed below:

   - CodeCell is Battery Powered & a USB cable is plugged in for charging
   - CodeCell is Battery Powered & a USB cable is plugged in for charging -
   during the battery low indication warning
   - If Serial connection is lost but USB power still active

The  USB_VOLTAGE is the threshold we use to indicate if the cable is
powered via USB or battery. The output voltage when USB powered, can vary
around 0.2V from one chip to another, so from our testing 4.1V is a good
limit.

POWER_INIT is being used internally as an initialization flag, for us to
detect which power stage the CodeCell is in, whether its battery power, usb
powered, or in charging stage.
POWER_BAT_CHRG_FULL indicates that the battery is fully charged

Looking forward for your response

Microbots Team

On Sun, 23 Feb 2025 at 23:35, James Megariotis ***@***.***>
wrote:

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

JamesMegariotis, 2025-02-24:
Hi,

I am currently using codecell library v1.2.6 and was using this version throughout the issues I encountered. We have a larger project that is not currently publicly available for use in AR/VR simulations, but this code supports a variety of esp32 based microcontrollers, IMUs and battery management systems. We added a very minimal amount of code to support the codecell microcontroller. This overall project has run in a stable manner on the other supported microcontrollers. The codecell also has nothing but the battery on it. So no peripheral hardware or other drivers are running. Only what is included on a stock codecell with IMU. The only unique code that was added for the code cell is below.

My initialization for the code cell in setup() was the following:
`myCodeCell.Init(MOTION_ROTATION_NO_MAG);`

In the loop() I was doing just doing the following:
```
// codecell IMU read code
if (myCodeCell.Run(50)) {  //Run every 50Hz
    myCodeCell.Motion_RotationNoMagRead(roll_f, pitch_f, yaw_f);
}
```

Roll pitch and yaw are then packaged and sent in our data packets. The only other call to the code cell library I used was the BatteryRead() function to populate battery voltage in our data packets and for display on a web server.

Upon removing the code cell library and using the adafruit BNO085 library for IMU and manually reading the battery voltage and charger IC state through analog and digital read, the code runs stable for hours, but any attempt to use the above few lines of code seems to lead to stability issues and resets within minutes when on battery power only. I assume it must either be sleeping and waking up or calling esp_restart, since all wifi connections are lost and our setup() code seemingly runs again, resetting certain timers/counters that only reset on startup.

Is calling the Run() function even required to be able to read the IMU throught this library? Because it seems my issue is definitely coming from there. I am also not super fond of the esp32 sleeping while charging. Is there a reason that run implements this? I only wonder because saving power while plugged in via usb seems like it would not be a major concern unless there was a hardware limitation or reason for doing so.

-James

microbotsio, 2025-02-25:
Hi James

Thanks for the clarification :)

We will try to replicate the bug and get back to you

Microbots Team

On Mon, 24 Feb 2025 at 16:44, James Megariotis ***@***.***>
wrote:

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

microbotsio, 2025-02-26:
Hi James

So far, we have not been able to replicate the issue, but we suspect it is related to the tolerance of the charging chip and ADC. We have identified possible root causes that could explain the behavior you observed - so we have released an update to the v1.2.7 library to prevent unnecessary resets related to charging.

Could you update to this new version and confirm whether the issue still persists?

microbotsio, 2025-03-15:
Hi James

Just checking if you have any update on this

microbotsio, 2025-04-09:
Since we haven’t heard back, we’re assuming the issue has been resolved.
If you have any further questions, please don’t hesitate to reopen the issue

Closed 2025-04-09.

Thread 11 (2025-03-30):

Function usage

Nakupenda-star, 2025-03-30:
The code `timerBegin(100000)` used in CodeCell.cpp reported an error during the compilation process. The function prototype is `hw_timer_t* timerBegin(uint8_t timer_num, uint16_t divider, bool count_up)`. Is this due to the version you used in the past, or did I misunderstand?

microbotsio, 2025-03-31:
Hi

Thanks for reaching out!

Can you confirm you have the latest esp32 board-library installed? The
CodeCell support v3.1.1 and above

Thanks
Team Microbots

On Sun, 30 Mar 2025 at 16:59, Nakupenda-star ***@***.***>
wrote:

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

microbotsio, 2025-04-04:
First, could you confirm if your device works with the Arduino IDE?

Our official CodeCell library is written in C++ and is primarily designed
for the Arduino IDE environment. If you’re using PlatformIO, it’s possible
you might need to write some custom code to interface properly with the
onboard sensors and peripherals, especially if PlatformIO doesn’t have the
latest ESP32 board libraries installed.

For reference, on Arduino IDE we recommend using ESP32 board support
package v3.1.1 or above, which includes the latest definitions and support
for the ESP32-C3.

As for the timerBegin() issue - The error likely comes from an outdated
board package, since the syntax and function signatures were updated in
recent ESP32 core versions. In the Arduino IDE with the latest version, the
code compiles as expected. So if you cannot update the esp32 package
library you could either not use the timer or modify it, to work on the
specific version you are using.

On Mon, 31 Mar 2025 at 16:25, Nakupenda-star ***@***.***>
wrote:

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

microbotsio, 2025-04-22:
Hi

Is there an update on this issue?

microbotsio, 2025-04-30:
As there’s been no response for several weeks, I’m closing this issue for now.

If the problem persists or you have more information to add, feel free to reopen it or open a new issue.

Thank you.

Closed 2025-04-30.

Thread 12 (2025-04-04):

loop reboot

openmotion, 2025-04-04:
hello randomly i have this problem with the board
do you think it's an hardware problem ?

>> CodeCell v1.2.7 Booting..
>> Initializing Sensors: E (2496) i2c.master: I2C transaction timeout detected
E (2497) i2c.master: probe device timeout. Please check if xfer_timeout_ms and pull-ups are correctly set up

>> Error: Motion Sensor not found - Check Hardware

microbotsio, 2025-04-04:
Hi

Thanks for reaching out! There was an issue on some devices, related to
this bug on software v1.2.7

Can you check if the issue occurs with the latest software update? v1.2.8

Thanks
Team Microbots

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

openmotion, 2025-04-04:
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

thanks i updated but same problem

```
>> CodeCell v1.2.8 Booting..
>> Initializing Sensors: E (3167) rmt: rmt_new_tx_channel(269): not able to power down in light sleep

>> Error: Motion Sensor not found - Check Hardware
```

microbotsio, 2025-04-04:
Can you share the code? It seems the device is going to sleep

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

openmotion, 2025-04-04:
i used the basic example, commented you the wifi part

```
#include <WiFi.h>
#include <CodeCell.h>
#include <BLEServer.h>
#include <BLE2902.h>
CodeCell myCodeCell;

const char* ssid = "xxx"; // Replace with your Wi-Fi name
const char* password = "xxx"; // Replace with your Wi-Fi password

float x = 0.0;  // Magnetic field on X-axis
float y = 0.0;  // Magnetic field on Y-axis
float z = 0.0;  // Magnetic field on Z-axis

void setup() {
  // put your setup code here, to run once:
    Serial.begin(9600);
  while(!Serial);

// WiFi.begin(ssid, password); // Connect to Wi-Fi

  //  Serial.print("Connecting to Wi-Fi");
   // while (WiFi.status() != WL_CONNECTED) {
    //    delay(500);
     //   Serial.print("."); // Print dots while connecting
    //}

  //  Serial.println("\nConnected!");
//    Serial.print("IP Address: ");
//  Serial.println(WiFi.localIP());
   Serial.println("start magnetometer");
    myCodeCell.Init(MOTION_MAGNETOMETER); // Initialize the magnetometer
}

void loop() {
  // put your main code here, to run repeatedly:
   //Serial.println("start");

  if (myCodeCell.Run(10)) { // Read at 10Hz (every 100ms)
    myCodeCell.Motion_MagnetometerRead(x, y, z); // Get magnetometer readings

     Serial.print("Mag X: "); Serial.print(x);
     Serial.print("  Y: "); Serial.print(y);
     Serial.print("  Z: "); Serial.println(z);
  }

}

```

microbotsio, 2025-04-07:
Hi

We are trying to replace the issue with your board - Can you confirm how
frequently it is happening with the v1.2.8 software? And if you have any
external sensors/modules connected to the I2C bus?

Thanks
Team Microbots

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

openmotion, 2025-04-07:
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

it's happening evertytime now
`>> CodeCell v1.2.8 Booting..
>> Initializing Sensors: E (2915) i2c.master: I2C transaction timeout detected
E (2915) i2c.master: probe device timeout. Please check if xfer_timeout_ms and pull-ups are correctly set up
E (2928) i2c.master: I2C hardware timeout detected
E (2928) i2c.master: probe device timeout. Please check if xfer_timeout_ms and pull-ups are correctly set up

>> Error: Motion Sensor not found - Check Hardware`

microbotsio, 2025-04-07:
Understood but can you confirm if you have any external sensors/modules
connected to the I2C bus? or if the sensor was damaged in some way?

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

openmotion, 2025-04-07:
> Understood but can you confirm if you have any external sensors/modules
> connected to the I2C bus? or if the sensor was damaged in some way?
> […](#)

nothing is connected to the I2C bus, i think the sensor is damaged
can you send me another board ?

microbotsio, 2025-04-07:
Can you send us your order details by email on ***@***.***

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

openmotion, 2025-04-07:
> Can you send us your order details by email on ***@***.***
> […](#)

yes just sended by email

Closed 2025-04-16.

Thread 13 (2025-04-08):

issues with the BNO88 sensor

msinaasappel, 2025-04-08:
From version 1.2.7 there seems to be something wrong with the i2c settings for the BN088. I got the following error after loading the script.

CodeCell v1.2.8 Booting..
Initializing Sensors: E (1519) i2c.master: I2C transaction timeout detected
E (1520) i2c.master: probe device timeout. Please check if xfer_timeout_ms and pull-ups are correctly set up
E (1533) i2c.master: I2C hardware timeout detected
E (1533) i2c.master: probe device timeout. Please check if xfer_timeout_ms and pull-ups are correctly set up

Error: Motion Sensor not found - Check Hardware

Additionally, the LED has turned solid red.
using 1.2.6 does not give these errors

microbotsio, 2025-04-09:
Hi

Thank you so much for reaching out

It seems we are having an issue on some devices with the v1.2.7/v1.2.8
software releases related to this matter

We are trying to fix it and push an new software release later this week
Thanks for you patiencence
[image: Logo]
Microbots Team
Miniaturized Robotics + Simplified Electronics
email: ***@***.***
www.microbots.io
[image: Twitter icon] <https://twitter.com/microbots_io>  [image: Instagram
icon] <https://www.instagram.com/microbots.io/>

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

microbotsio, 2025-04-09:
Hi

We've successfully replicated the issue you reported.

To help us further understand the situation, could you please confirm
whether you're using the new ESP v3.2.0 board package by Espressif?
Currently, this update isn't compatible with the latest 1.2.8 software due
to some changes in the I2C driver.

As mentioned, we're actively updating the library to ensure compatibility.
In the meantime, you can continue using the CodeCell with the previous
v3.1.3 ESP board package by Espressif.

Thank you for your patience. We'll keep you updated as soon as the upgrade
is complete.

Microbots Team

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

msinaasappel, 2025-04-09:
Hi,

Yes, I can confirm that I used the ESP v3.2.0

microbotsio, 2025-04-22:
We just released v1.2.9 which is now compatible with latest ESP v3.2.0 board package

Let us know if you have any other questions

Closed 2025-04-22.

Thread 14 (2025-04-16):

Button failure to when adding rotational data.

Uruglee2, 2025-04-16:
Hardware Setup:

Connect CodeCell/BNO085 sensor to the ESP32 according to standard wiring (e.g., I2C).
Connect a standard pushbutton between ESP32 GPIO Pin 6 and GND. (Pin 5 also shows the issue).
(Optional) Connect an LED to GPIO Pin 2 for status.

Problem:
When I press the button nothing happens.
Is there an issue in my code or hardware ie. the BNO085 fusion sensor?
If I write Isolation code for the LED and the button, the GPIO works however, when I introduce this to the Rotation data the button is no responsive.
The code I wrote for the BNO085 and works fine. It is just when I introduce a button press to the mess (script) I get nothing and freezes and will not let me proceed.

Question: (dumb question): previously, I was able to incorporate a button press to store the fusion sensor data at that instance, giving me a reference number. After the recent updates I have not been able to get anything working again together.

//sample code for duplicating the issue//

#include <CodeCell.h>

const int BUTTON_PIN = 6; // Pin exhibiting the issue
const int STATUS_LED_PIN = 2;
CodeCell myCodeCell;
unsigned long lastCheckTime = 0;

void setup() {
  Serial.begin(115200);
  while (!Serial && millis() < 2000);
  Serial.println("\n--- CodeCell GPIO Conflict Test ---");

  pinMode(STATUS_LED_PIN, OUTPUT);
  digitalWrite(STATUS_LED_PIN, LOW); // LED Off initially

  Serial.print("Configuring Button Pin "); Serial.println(BUTTON_PIN);
  pinMode(BUTTON_PIN, INPUT_PULLUP); // Configure button pin

  // Allow time for setup before sensor init
  Serial.println("Brief delay before sensor init...");
  delay(1000);
  int initialRead = digitalRead(BUTTON_PIN);
  Serial.print("Pin state BEFORE Init: "); Serial.println(initialRead == HIGH ? "HIGH (Expected)" : "LOW (Unexpected!)");

  Serial.println("Initializing CodeCell (MOTION_ROTATION)...");
  myCodeCell.Init(MOTION_ROTATION);
  Serial.println("CodeCell Initialization Complete.");

  // Allow time for stabilization after init
  Serial.println("Adding 1s stabilization delay...");
  delay(1000);
  Serial.println("Stabilization complete. Starting loop checks.");
  lastCheckTime = millis();
}

void loop() {
  unsigned long currentTime = millis();

  // Check button state periodically
  if (currentTime - lastCheckTime >= 500) { // Check every 500ms
    int currentButtonState = digitalRead(BUTTON_PIN);
    Serial.print("Timestamp: "); Serial.print(currentTime);
    Serial.print(" | Raw Pin "); Serial.print(BUTTON_PIN);
    Serial.print(" Read: "); Serial.println(currentButtonState);

    // Blink LED if LOW is read (to visually confirm)
    if (currentButtonState == LOW) {
        digitalWrite(STATUS_LED_PIN, !digitalRead(STATUS_LED_PIN)); // Blink LED
    } else {
        digitalWrite(STATUS_LED_PIN, LOW); // Keep LED off if HIGH
    }
    lastCheckTime = currentTime;
  }

  // Keep sensor running (even if not explicitly reading rotation data here)
  myCodeCell.Run(50); // Run at 50Hz
}

microbotsio, 2025-04-16:
Hi! Thanks for the detailed write-up - The main thing that stands out is that `myCodeCell.Init()` must be called before setting up your pins. In your current sketch, you're calling `pinMode(BUTTON_PIN, INPUT_PULLUP)` before initializing CodeCell, which is likely causing the issue. CodeCell internally configures its pins during `Init()`, and anything set beforehand may be overwritten.

Here’s a simplified version of your code that should work more reliably:

```cpp
#include <CodeCell.h>

CodeCell myCodeCell;

#define BUTTON_PIN 6U
#define STATUS_LED_PIN 2U

void setup() {
  Serial.begin(115200);
  myCodeCell.Init(MOTION_ROTATION); // Initialize CodeCell first

  // No need to call pinMode() yourself
}

void loop() {
  if (myCodeCell.Run(50)) {  // Run at 50Hz
    if (myCodeCell.pinRead(BUTTON_PIN)) {
      myCodeCell.pinWrite(STATUS_LED_PIN, HIGH);
    } else {
      myCodeCell.pinWrite(STATUS_LED_PIN, LOW);
    }
  }
}
```

Other tips that might help:
- Try using a pull-up or pull-down resistor with your button to make sure the logic level is clean and you're properly detecting rising/falling edges.
- You can skip the usual `pinMode()` setup as `myCodeCell.pinRead()` and `pinWrite()` work directly without extra initialization.
- If you want a consistent loop timing, use `myCodeCell.Run(50)` that runs the loop at 50Hz

Let us know if this works for you or if you're still seeing issues. Happy to help further!

Uruglee2, 2025-04-18:
Thank you I am taking that into consideration and I am also taking into consideration my ability to think clearly with minimal sleep.
A simple mistake in pins is all it takes to have a couple hard days.
I appreciate the great support, Great work!!.

L

microbotsio, 2025-04-19:
No worries - we've all been there!

Glad it's getting sorted, and appreciate the kind words!

Closed 2025-04-19.

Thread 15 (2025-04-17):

Powering CodeCell using the castellated pins

alexfernandez, 2025-04-17:
Hi, I'd like to power my CodeCells using the castellated pins instead of using the JST connector. Is it possible? I guess the 5V0 pin can take 5V, but I'm using a LiPo battery in my design.

Can the CodeCell be powered using a 1S LiPo battery using the 4V4 and GND pins? I'd try it out but don't want to fry them 😅

alexfernandez, 2025-04-17:
For anyone who comes here looking for an answer: yes, you can input ~4.2 V via the VO (4.4V) and GND pins.

microbotsio, 2025-04-17:
Hi

Thanks for reaching out!

Yes, it will work, but we don’t recommend soldering the battery directly to
the Vo pin. That’s because Vo is regulated through the battery management
chip, not directly connected to the battery. So if you connect a battery
there, you'd be bypassing the protection and charging circuitry. When
connecting the usb this can result in incorrect charging voltage and
potentially harm the battery.

Vin, on the other hand, is directly connected to the USB charging voltage.

So while connecting a LiPo to Vo or Vin can power the CodeCell, it’s
important to note that doing so while the USB is also connected, could
damage the battery.

Our recommendation is to use the onboard connector, which ensures safe
charging and operation through the battery management chip.

Let us know if you have any other questions!

Team Microbots

On Thu, 17 Apr 2025 at 16:45, Alex Fernández ***@***.***>
wrote:

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

alexfernandez, 2025-04-23:
Thanks a lot for the quick response! I will try using the onboard connector 😊

Closed 2025-04-17.

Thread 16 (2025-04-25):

Non-void functions end without a return.

sbaeder, 2025-04-25:
Using the "latest" library in the aurduino IDE, and got "warnings" as an error on 4 routines that have an if statement that if true will return a value, but on the "else", they just print an error.

there are 4 of them... I added the "return of a zero value" on the failure to be  enabled.  That fixed the compile errors that prevented me from completing any of the examples.

Thanks

`bool CodeCell::Motion_TapRead() {
  if ((_msense & MOTION_TAP_DETECTOR) == MOTION_TAP_DETECTOR) {
    return _tap_data;
  } else {
    Serial.println(">> Error: Motion Tap Sensor not Activated");
	return 0;
  }
}

uint16_t CodeCell::Motion_StepCounterRead() {
  if ((_msense & MOTION_STEP_COUNTER) == MOTION_STEP_COUNTER) {
    return _step_data;
  } else {
    Serial.println(">> Error: Motion Step Sensor not Activated");
	return 0;
  }
}

uint16_t CodeCell::Motion_StateRead() {
  if ((_msense & MOTION_STATE) == MOTION_STATE) {
    return _mstate_data;
  } else {
    Serial.println(">> Error: Motion State Sensor not Activated");
	return 0;
  }
}

uint16_t CodeCell::Motion_ActivityRead() {
  if ((_msense & MOTION_ACTIVITY) == MOTION_ACTIVITY) {
    return _activity_data;
  } else {
    Serial.println(">> Error: Motion Activity Sensor not Activated");
	return 0;
  }
}
`

microbotsio, 2025-04-26:
Thanks for pointing this out - we really appreciate it! This has been fixed in v3.0.1.

The return statements were only missing in those cases where the sensor wasn’t properly initialized, so it shouldn't effect unless there is an error. Make sure to always initialize the sensors you're using before calling those functions. For example: myCodeCell.Init(MOTION_STEP_COUNTER);

Let us know if you still run into any issues!

sbaeder, 2025-04-26:
thanks - Yes, it wouldn't have been an error, but compiler was flagging it as a warning that it deemed an error.  Thanks for quick response.

Closed 2025-04-26.

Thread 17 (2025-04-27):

CodeCell dimensions

alexfernandez, 2025-04-27:
Hi, I'm trying to integrate CodeCell into a drone design, but I have not found an engineering diagram with all dimensions. I can measure them myself but the results are not very exact, and I cannot get good measures from the 3d model either.

* Do you have an engineering diagram for the CodeCell with all measurements?
* Failing that, what is the distance between the border and the pin centers? I have measured it to be 1.27 mm approx.
* What is the distance between the pins on opposing sides? I have measured 15.90 mm approx.

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

Thanks in advance!

microbotsio, 2025-04-28:
Hi
Thanks for reaching out - the 3d model of the CodeCell is available here - https://github.com/microbotsio/CodeCell/tree/main/hardware

You can also find the measurements in the image below

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

Let us know if you have further questions! Happy Building :)

alexfernandez, 2025-04-29:
Thanks for your prompt answer! While those are useful, it would be great to have a proper engineering drawing: https://en.wikipedia.org/wiki/Engineering_drawing less error-prone than the 3d model and more complete than the drawing.

microbotsio, 2025-04-30:
Thanks for your message!

The 3D model is accurate, but for your convenience, please find a proper engineering drawing here:
https://github.com/microbotsio/CodeCell/blob/main/hardware/codecell%20drawing.png

alexfernandez, 2025-04-30:
That is awesome! Thanks a lot.

For anyone coming here to integrate CodeCells into their own PCB designs, the distance between consecutive holes is 2.54 mm, and the distance between hole and border is 1.27 mm -> the distance between holes on opposing sides is 15.96 mm (18.5-1.27x2).

Closed 2025-04-30.

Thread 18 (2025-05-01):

Wakeup Compilation Error

mhl787156, 2025-05-01:
Hi!

I've been trying to setup a CodeCell today and I've gotten a weird compilation error, was wondering if you've seen this before:

```
CodeCell\src\CodeCell.cpp: In member function 'void CodeCell::USBSleep()':
CodeCell\src\CodeCell.cpp:257:45: error: 'ESP_GPIO_WAKEUP_GPIO_LOW' was not declared in this scope; did you mean 'ESP_EXT1_WAKEUP_ALL_LOW'?
  257 |   esp_deep_sleep_enable_gpio_wakeup(1 << 0, ESP_GPIO_WAKEUP_GPIO_LOW); /*Set Gpio0 as wakeup pin*/
      |                                             ^~~~~~~~~~~~~~~~~~~~~~~~
      |                                             ESP_EXT1_WAKEUP_ALL_LOW
c:\Users\CodeCell\src\CodeCell.cpp:257:3: error: 'esp_deep_sleep_enable_gpio_wakeup' was not declared in this scope; did you mean 'esp_sleep_enable_gpio_wakeup'?
  257 |   esp_deep_sleep_enable_gpio_wakeup(1 << 0, ESP_GPIO_WAKEUP_GPIO_LOW); /*Set Gpio0 as wakeup pin*/
      |   ^~~~~~~~~~~~~~~~~~~~~~~~~~~~~~~~~
      |   esp_sleep_enable_gpio_wakeup
exit status 1

Compilation error: exit status 1
```

I have esp32 by Espressif Systems v3.2.0, CodeCell Library v1.3.1

Building on Windows 11.

microbotsio, 2025-05-02:
Hi

Thanks for reaching out

Can you share your code? can you confirm how you are using the
myCodeCell.USBSleep() function?

Thanks
Team Microbots

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

mhl787156, 2025-05-02:
Hi

I was using some custom code, but I just tried it with the GettingStarted Example and it raised the same issue.

To me it looks like a compilation error within the CodeCell Library itself, perhaps a version mismatch or an update in the esp32c3 library causing the enums to be switched around.

Investigating a bit more, something is odd with my laptop setup.
I also tried it with esp32 library v3.1.0 and v3.0.0 and it failed, Codecell library 1.2.7 and 1.3.1 also failed.

On a different machine
I have gotten it to work with CodeCell library v1.2.7/ esp32 3.2.0. A colleague also got the same.

... very odd!

mhl787156, 2025-05-02:
Okay, got to the bottom of it, apologies it was me - I had selected `ESP32 Dev Module` instead of `ESP32C3 Dev Module`, and it was therefore compiling against the wrong firmware. Apologies all solved and hope it helps someone else out...

microbotsio, 2025-05-02:
No worries, thanks for the update and glad you resolved the issue :)

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

Closed 2025-05-02.

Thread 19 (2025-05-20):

Issue with GettingStarted Sketch

MomoRazor, 2025-05-20:
Hi guys.

Firstly wanted to congratulate you on how great this project looks. I wish you all the best in continuing to improve on it, and making electronics more accessible to hobbists.

I've been playing around with a CodeCell lately, and can't seem to get the GettingStarted sketch to work. The following is all the information I can think of getting, let me know if there should be more:

Error - ...\libraries\CodeCell\src\CodeCell.cpp: In member function 'void CodeCell::USBSleep()':
c:\Users\Maurovic Cachia\OneDrive\Documents\Arduino\libraries\CodeCell\src\CodeCell.cpp:257:45: error: 'ESP_GPIO_WAKEUP_GPIO_LOW' was not declared in this scope; did you mean 'ESP_EXT1_WAKEUP_ANY_LOW'?

IDE - Arduino IDE
CodeCell library version - 1.3.2
Board selected and detected by IDE - Namino Arancio

Thanks in advance for your help :)

microbotsio, 2025-05-21:
Hi

Thanks for reaching out - we're glad you like our CodeCell project!

Can you confirm you are using the latest v3.2.0 ESP32 board manager? Also
make sure you are selecting the correct board -  Tools > Board > ESP32C3
Dev Module.

More debugging information can be found here -
https://microbots.io/blogs/codecell/debugging-codecell

Let us know if this resolves the issue :)

Team Microbots

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

MomoRazor, 2025-05-21:
Thanks for replying. I've changed the information you mentioned and have made progress. If I can suggest something, seeing as some of the information in https://microbots.io/blogs/codecell/debugging-codecell is actually setup (namely the stuff with regards to the first Arduino IDE runs), maybe they ought to be moved to a Getting Started Tutorial, along with all the other tutorials :).

Regardless, I have made progress but I'm still running into an issue, although it does seem a bit weird and I'm not entirely sure its a CodeCell issue. Essentially, when I attempt to flash any script, for example the GettingStarted one, i receive the following issue:

```
A serial exception error occurred: Cannot configure port, something went wrong. Original message: PermissionError(13, 'A device attached to the system is not functioning.', None, 31)
Note: This error originates from pySerial. It is likely not a problem with esptool, but with the hardware connection or drivers.
For troubleshooting steps visit: https://docs.espressif.com/projects/esptool/en/latest/troubleshooting.html
```

I've followed the troubleshooting suggestions here and have changed ports, cabels and even microcontrollers (I made sure that an other project of mine that doesn't use CodeCell was still uploading properly) and I could not find the culprit so far. I have also tried rebooting my system, and reinstalling USB drivers, but to no avail.

Not sure if you might have any insight as to what might be the issue here. I will be continuing to try and find the issue as well, and will post here if I find a solution for it.

Thank you!

MomoRazor, 2025-05-22:
Just wanted to return back to this to mention that I have managed to fix this issue, sort of.

I ended up switching the system I was working on to one that runs on Linux (Ubunt 24.04.2 LTS specifically) and everything worked properly immediately, indicating that it is probably something to do with the way my Windows system is setup somehow.

I will leave it to you to close this issue if you feel like this shouldn't be investigated any further.

MomoRazor, 2025-05-22:
Hi guys, sorry to have to re-open this issue, but I've run into some new issues, and I'm not sure if they are related to the previous issue, or some of the steps I took in attempt to fix.

So as mentioned in the previous message, I have managed to get the chip to flash new code, but I'm not sure which examples should be working and which shouldn't.

From the CodeCell examples, while Light ones seem to be working, it is clear that all Motion examples are not, but that is to be expected since my CodeCell does not have the motion sensor onboard,

Then I moved on to the CodeCell MicroLink examples, but apart from the LightSense example, which from what I gather was the example already present on the board, none seem to worki. When I successfully upload any other example, the blue LED turns off or does not blink, and the application is unable to find the CodeCell. I have not tried all the other examples, but so far all of them have had the same result.

I did run a couple of power cycles, and used your instructions to attempt to reset the chip (grounding the SCL pin), but this does not seem to change behaviour.

Thanks in advance for any advice regarding this!

microbotsio, 2025-05-24:
Hi,

Thanks again for the updates and for sharing all the detailed info!

Understood, and appreciate the suggestion about the tutorial structure, you are right, we will do our best to make it better - If your intrested we do have a YouTube video covering the initial Arduino setup here: https://www.youtube.com/watch?v=DQQVjrn1RQo&t=51s

It’s almost a year old now, but we’re working on updating it soon. But the core setup is still valid if you're looking to revisit those early steps.

The flashing issue on Windows definitely sounds strange. Since it works fine on our end (we also use Windows), it might indeed be driver-related. Reinstalling the Arduino IDE or checking for any COM port conflicts might help if you ever go back to the Windows machine. But good to hear everything’s working on Ubuntu now!

Regarding the MicroLink examples: if you’re using a CodeCell Light (without the motion sensor), then the motion examples will naturally fail - running them should throw an error over serial that the sensor is missing. That’s expected.

To get MicroLink examples running on CodeCell Light, just make sure:

1. Your setup starts with:

   ```cpp
   myCodeCell.Init(LIGHT);
   ```
2. And, remove any motion sensor calls used to update app metrics. For example, replace:

   ```cpp
   // Read rotation data from the motion sensor
   myCodeCell.Motion_RotationRead(Roll, Pitch, Yaw);

   // Show sensor readings (battery level, light sensor, yaw) in the app
   myMicroLink.ShowSensors(myCodeCell.BatteryLevelRead(), myCodeCell.Light_ProximityRead(), Yaw);
   ```

   with just:

   ```cpp
   // Show sensor readings (battery level, light sensor) in the app
   myMicroLink.ShowSensors(myCodeCell.BatteryLevelRead(), myCodeCell.Light_ProximityRead(), 0);
   ```

Some of the examples that do not use the motion sensor, will work right away. But that should allow the other MicroLink examples (except ActivityTracker) to work properly.

Let us know how that goes
Thanks,
Team Microbots

MomoRazor, 2025-05-24:
> Regarding the Windows issue, we just noticed there was a similar issue reported a couple of weeks ago on our GitHub: [#18](https://github.com/microbotsio/CodeCell/issues/18)
>
> Could you please confirm that in the Arduino IDE, under Tools > Board, you’ve selected ESP32C3 Dev Module and not ESP32 Dev Module?

I've retried on windows just in case I had made this mistake, but it still persisted. I do think it might be an issue with COM port conflicts, and I'll probably be investigating it further, but in any case, it does not seem to be related to CodeCell really. I will keep you posted if I find out otherwise.

> Some of the examples that do not use the motion sensor, will work right away. But that should allow the other MicroLink examples (except ActivityTracker) to work properly.

This is where I'm having issues. So far I've tested the following MicroLink examples and got the following results:

- DriverCell_Slider: Uploads ok, however bluetooth is not able to find the CodeCell, LED is on solid blue.
- FlatFlap_Slider: Uploads ok, however bluetooth is not able to find the CodeCell, LED is on solid blue.
- GettingStarted: Uploads ok, however bluetooth is not able to find the CodeCell, LED is on solid blue.
- LightSense: Uploads ok, and bluetooth connects, allowing me to add the CodeCell to the list. LED is flashing blue.
- MotorCell_Slider: After installing the MotorCell library, uploads ok, and bluetooth connects, allowing me to add the CodeCell to the list. LED is controlled by logic so not worth mentioning here.
- Motors_Joystick: After installing the DriveCell library, uploads ok, however bluetooth is not able to find the CodeCell, LED is turned off completely.

Just to be clear also, here when I say bluetooth is not able to find the CodeCell, I'm trying to add the CodeCell from scratch, having deleted when it was found using the LightSense example.

After reviewing the code, I do see two key difference in the ones that worked and the ones that did not. Its the myCodeCell.Run frequency at the start of the loop function (its 10 when it works and 100 when it doesn't) and also the myCodeCell.Init argument. While the .Run function seems to work either way, the Init seems to be the reason, and in hindsight, I might be understanding that it should be LIGHT only when i'm using a CodeCell Light, correct? I have managed to make Motors_Joystick work after changing the arguments of myCodeCel.Init to just LIGHT.

If this is the issue, I would think its important to mention in the documentation for those who have a CodeCell Light, and I would also check if this issue happens as well for people using the full CodeCell when using LightSense and MotorCell_Slider.

Thank you :)

MomoRazor, 2025-05-26:
Thanks for the help, all is working now, after doing the code changes required as you said. Not sure if the CodeCell Light is a limited run product or if its going to continue being sold, but if it is, I do suggest some specific help somewhere to make sure these code changes are more obvious to people trying out the CodeCell Light first.

If you deem it worth it, I can create a PR with the examples that can work on the CodeCell Light, fixed to do so without user edits. I can also this on the MicroLink repo.

Thanks again for the help and for this project :)!

microbotsio, 2025-05-28:
You're very welcome - glad to hear it's working now! And thanks a lot for the thoughtful suggestion about making things clearer for CodeCell Light users. We really appreciate the feedback, and it's something we’ll keep in mind as we continue improving the docs and examples.

Thanks again for diving in and for the kind words!

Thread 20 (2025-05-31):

Sleep / Wake not working

filip-dobrocky, 2025-05-31:
There seems to be a problem in the implementation of the sleep / wake function, the example `Light_SleepExample.ino` itself is not working:
```
#include <CodeCell.h>

CodeCell myCodeCell;

void setup() {
  Serial.begin(115200);

  delay(60);//Waking up from Sleep - add a small delay for Serial
  if (myCodeCell.WakeUpCheck()) {
    // Initialize light sensor
    while (myCodeCell.Light_Init() == 1) {
      delay(1);
      myCodeCell.LightReset(); //If sensor not responding, reset it
    }
    delay(40);
    myCodeCell.Light_Read();//Read value from light sensor
    if (myCodeCell.Light_ProximityRead() < 10) {
      Serial.println("Going to sleep");
      myCodeCell.Sleep(1); //If Proxity still not detected go back to sleep & check again after 1 sec
    }
  }

  myCodeCell.Init(LIGHT); //Time to wake up - Initializes all CodeCell peripherals
  Serial.println("Initialized");
}

void loop() {
  if (myCodeCell.Run(10)) {  //Run every 10Hz
    if (myCodeCell.Light_ProximityRead() < 10) {
      Serial.println("Going to sleep");
      myCodeCell.Sleep(1); /*If Proxity not detected go to sleep & check again after 1 sec*/
    }
  }
}
```
(I just added some serial writes for debugging)

Using  Arduino IDE 2.3.6 on Linux, arduino-esp32 3.3.0-alpha1, CodeCell 1.3.2, setting Core Debug Level to "Debug", I get the following output:

```
=========== Before Setup Start ===========
Chip Info:
------------------------------------------
  Model             : ESP32-C3
  Package           : 0
  Revision          : 0.04
  Cores             : 1
  CPU Frequency     : 160 MHz
  XTAL Frequency    : 40 MHz
  Features Bitfield : 0x00000012
  Embedded Flash    : No
  Embedded PSRAM    : No
  2.4GHz WiFi       : Yes
  Classic BT        : No
  BT Low Energy     : Yes
  IEEE 802.15.4     : No
------------------------------------------
INTERNAL Memory Info:
------------------------------------------
  Total Size        :   318408 B ( 310.9 KB)
  Free Bytes        :   282768 B ( 276.1 KB)
  Allocated Bytes   :    31672 B (  30.9 KB)
  Minimum Free Bytes:   277792 B ( 271.3 KB)
  Largest Free Block:   139252 B ( 136.0 KB)
------------------------------------------
Flash Info:
------------------------------------------
  Chip Size         :  4194304 B (4 MB)
  Block Size        :    65536 B (  64.0 KB)
  Sector Size       :     4096 B (   4.0 KB)
  Page Size         :      256 B (   0.2 KB)
  Bus Speed         : 80 MHz
  Bus Mode          : QIO
------------------------------------------
Partitions Info:
------------------------------------------
                nvs : addr: 0x00009000, size:    20.0 KB, type: DATA, subtype: NVS
            otadata : addr: 0x0000E000, size:     8.0 KB, type: DATA, subtype: OTA
               app0 : addr: 0x00010000, size:  1280.0 KB, type:  APP, subtype: OTA_0
               app1 : addr: 0x00150000, size:  1280.0 KB, type:  APP, subtype: OTA_1
             spiffs : addr: 0x00290000, size:  1408.0 KB, type: DATA, subtype: SPIFFS
           coredump : addr: 0x003F0000, size:    64.0 KB, type: DATA, subtype: COREDUMP
------------------------------------------
Software Info:
------------------------------------------
  Compile Date/Time : May 31 2025 11:51:35
  Compile Host OS   : linux
  ESP-IDF Version   : v5.5-dev-3129-gd930a386da-dirty
  Arduino Version   : 3.3.0
------------------------------------------
Board Info:
------------------------------------------
  Arduino Board     : CODECELLC3
  Arduino Variant   : codecell
  Arduino FQBN      : esp32:esp32:codecell:UploadSpeed=921600,CDCOnBoot=cdc,CPUFreq=160,FlashFreq=80,FlashMode=qio,FlashSize=4M,PartitionScheme=default,DebugLevel=debug,EraseFlash=none,JTAGAdapter=builtin,ZigbeeMode=default
============ Before Setup End ============
[   667][I][esp32-hal-periman.c:141] perimanSetPinBus(): Pin 18 already has type USB_DM (38) with bus 0x3fc917a0
[   668][I][esp32-hal-periman.c:141] perimanSetPinBus(): Pin 19 already has type USB_DP (39) with bus 0x3fc917a0

>> CodeCell v1.3.2 Booting..
>> Initializing Sensors: [  2128][I][esp32-hal-i2c-ng.c:105] i2cInit(): Initializing I2C Master: num=0 sda=8 scl=9 freq=400000
Light Activated
[  2132][W][esp32-hal-rgb-led.c:21] neopixelWrite(): neopixelWrite() is deprecated. Use rgbLedWrite().
[  2133][W][esp32-hal-rgb-led.c:21] neopixelWrite(): neopixelWrite() is deprecated. Use rgbLedWrite().
[  2213][W][esp32-hal-rgb-led.c:21] neopixelWrite(): neopixelWrite() is deprecated. Use rgbLedWrite().
[  2293][W][esp32-hal-rgb-led.c:21] neopixelWrite(): neopixelWrite() is deprecated. Use rgbLedWrite().
[  2373][W][esp32-hal-rgb-led.c:21] neopixelWrite(): neopixelWrite() is deprecated. Use rgbLedWrite().
>> Reading Sensors: Proximity: 14361 cts | White: 823 lx | Ambient: 322 lx |
[  2455][D][esp32-hal-adc.c:272] __analogRead(): Calling __analogInit! pin = 4
Initialized
=========== After Setup Start ============
INTERNAL Memory Info:
------------------------------------------
  Total Size        :   318408 B ( 310.9 KB)
  Free Bytes        :   278508 B ( 272.0 KB)
  Allocated Bytes   :    35244 B (  34.4 KB)
  Minimum Free Bytes:   277792 B ( 271.3 KB)
  Largest Free Block:   139252 B ( 136.0 KB)
------------------------------------------
GPIO Info:
------------------------------------------
  GPIO : BUS_TYPE[bus/unit][chan]
  --------------------------------------
     0 : GPIO
     1 : GPIO
     2 : GPIO
     3 : GPIO
     4 : ADC_ONESHOT[0][4]
     5 : GPIO
     6 : GPIO
     7 : GPIO
     8 : I2C_MASTER_SDA[0]
     9 : I2C_MASTER_SCL[0]
    10 : RMT_TX
    18 : USB_DM
    19 : USB_DP
    20 : UART_RX[0]
    21 : UART_TX[0]
============ After Setup End =============
>> Sampling Rate: 10Hz
[  2485][W][esp32-hal-rgb-led.c:21] neopixelWrite(): neopixelWrite() is deprecated. Use rgbLedWrite().
>> Power Status: Running from USB Power
[  2555][W][esp32-hal-rgb-led.c:21] neopixelWrite(): neopixelWrite() is deprecated. Use rgbLedWrite().
[  2655][W][esp32-hal-rgb-led.c:21] neopixelWrite(): neopixelWrite() is deprecated. Use rgbLedWrite().
[  2755][W][esp32-hal-rgb-led.c:21] neopixelWrite(): neopixelWrite() is deprecated. Use rgbLedWrite().
[  2855][W][esp32-hal-rgb-led.c:21] neopixelWrite(): neopixelWrite() is deprecated. Use rgbLedWrite().
```
...
```
Going to sleep
[  4956][E][esp32-hal-gpio.c:176] __digitalWrite(): IO 10 is not set as GPIO. Execute digitalMode(10, OUTPUT) first.
[  4957][W][esp32-hal-rgb-led.c:21] neopixelWrite(): neopixelWrite() is deprecated. Use rgbLedWrite().
```

Then, when trying to wake up:
```
============ Before Setup End ============
[   697][I][esp32-hal-periman.c:141] perimanSetPinBus(): Pin 18 already has type USB_DM (38) with bus 0x3fc917a0
[   698][I][esp32-hal-periman.c:141] perimanSetPinBus(): Pin 19 already has type USB_DP (39) with bus 0x3fc917a0
[   758][I][esp32-hal-i2c-ng.c:105] i2cInit(): Initializing I2C Master: num=0 sda=8 scl=9 freq=400000
>> Error: Light Sensor not Activated
Going to sleep
[   801][E][esp32-hal-gpio.c:176] __digitalWrite(): IO 10 is not set as GPIO. Execute digitalMode(10, OUTPUT) first.
[   801][W][esp32-hal-rgb-led.c:21] neopixelWrite(): neopixelWrite() is deprecated. Use rgbLedWrite().
```

I believe the error ` __digitalWrite(): IO 10 is not set as GPIO. Execute digitalMode(10, OUTPUT) first` is caused by this part of the `CodeCell::Sleep()` method:
```
digitalWrite(10, LOW);
pinMode(10, INPUT);
```
as the `digitalWrite` is being called without setting `pinMode` first. I tried swapping these lines, the error disappeared, but still the problem on WakeUp remains (`Error: Light Sensor not Activated`).

Therefore, it fails to wake up, and continues going to sleep.

filip-dobrocky, 2025-05-31:
When replacing the call to initialize the light sensor by `myCodeCell.Init(LIGHT);`, it works as expected:
```
void setup() {
  Serial.begin(115200);

  delay(60);//Waking up from Sleep - add a small delay for Serial
  if (myCodeCell.WakeUpCheck()) {
    // Initialize light sensor
    myCodeCell.Init(LIGHT);
    delay(40);
    myCodeCell.Light_Read();//Read value from light sensor
    if (myCodeCell.Light_ProximityRead() < 10) {
      Serial.println("Going to sleep");
      myCodeCell.Sleep(1); //If Proxity still not detected go back to sleep & check again after 1 sec
    }
  }

  myCodeCell.Init(LIGHT); //Time to wake up - Initializes all CodeCell peripherals
  Serial.println("Initialized");
}
```

The problem is, that the method `CodeCell::Light_Init()` does not set the class variable `_mense`, which `Light_ProximityRead()` checks for.

Honestly, the library is pretty confusing. To me it seems, that `Light_Init()` should be a private method and the initialization should only be done externally by calling the `Init()` method.

microbotsio, 2025-06-03:
Hi

Thanks you so much for reaching out and pointing this out

We are trying to recreate the problem, and will get back to you with a fix

microbotsio, 2025-06-05:
Hi,

Thanks for your patience and for pointing this out :)

We were able to replicate the issue and have resolved it in version 1.3.3

Thanks
Team Microbots

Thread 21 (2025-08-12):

IOS App does not display correctly

Tokn59, 2025-08-12:
IOS : Latest build, iPhone 12+ running the MicroLink App does not display correctly. See attached screenshot.

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

microbotsio, 2025-08-12:
Hi

Thanks for reaching out - Can you share you code? So that we can understand what you are trying to display

Team Microbots

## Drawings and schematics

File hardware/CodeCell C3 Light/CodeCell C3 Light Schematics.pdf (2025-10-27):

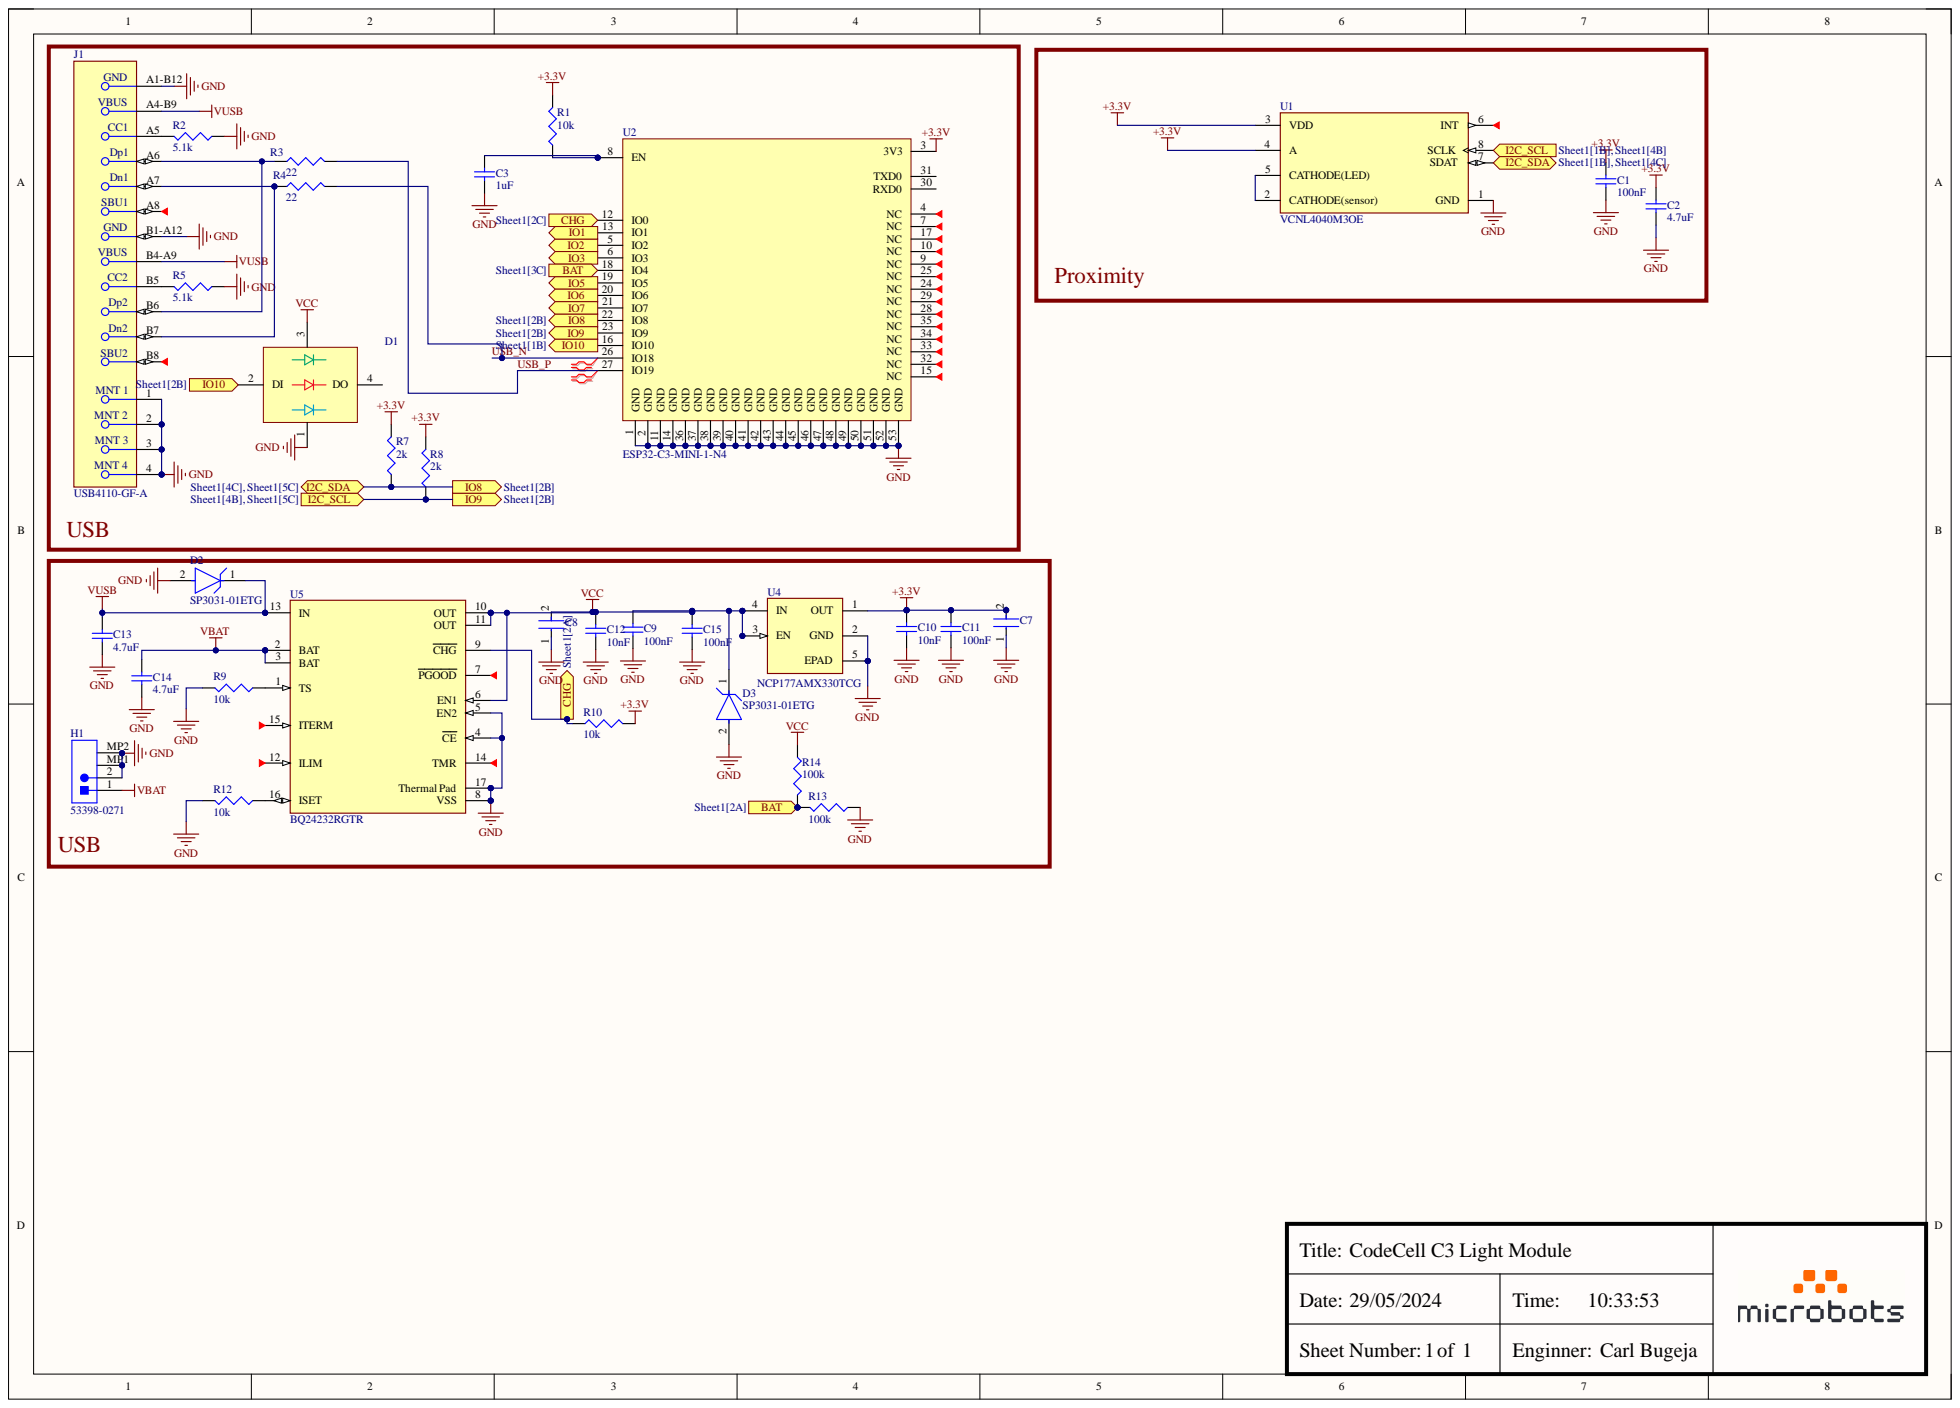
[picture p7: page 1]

Title : CodeCell C3 Light Module

Date : 29/05/202 41of | Time : 10:33:5 3

Sheet Number: 1 | Enginner : Carl Bugeja

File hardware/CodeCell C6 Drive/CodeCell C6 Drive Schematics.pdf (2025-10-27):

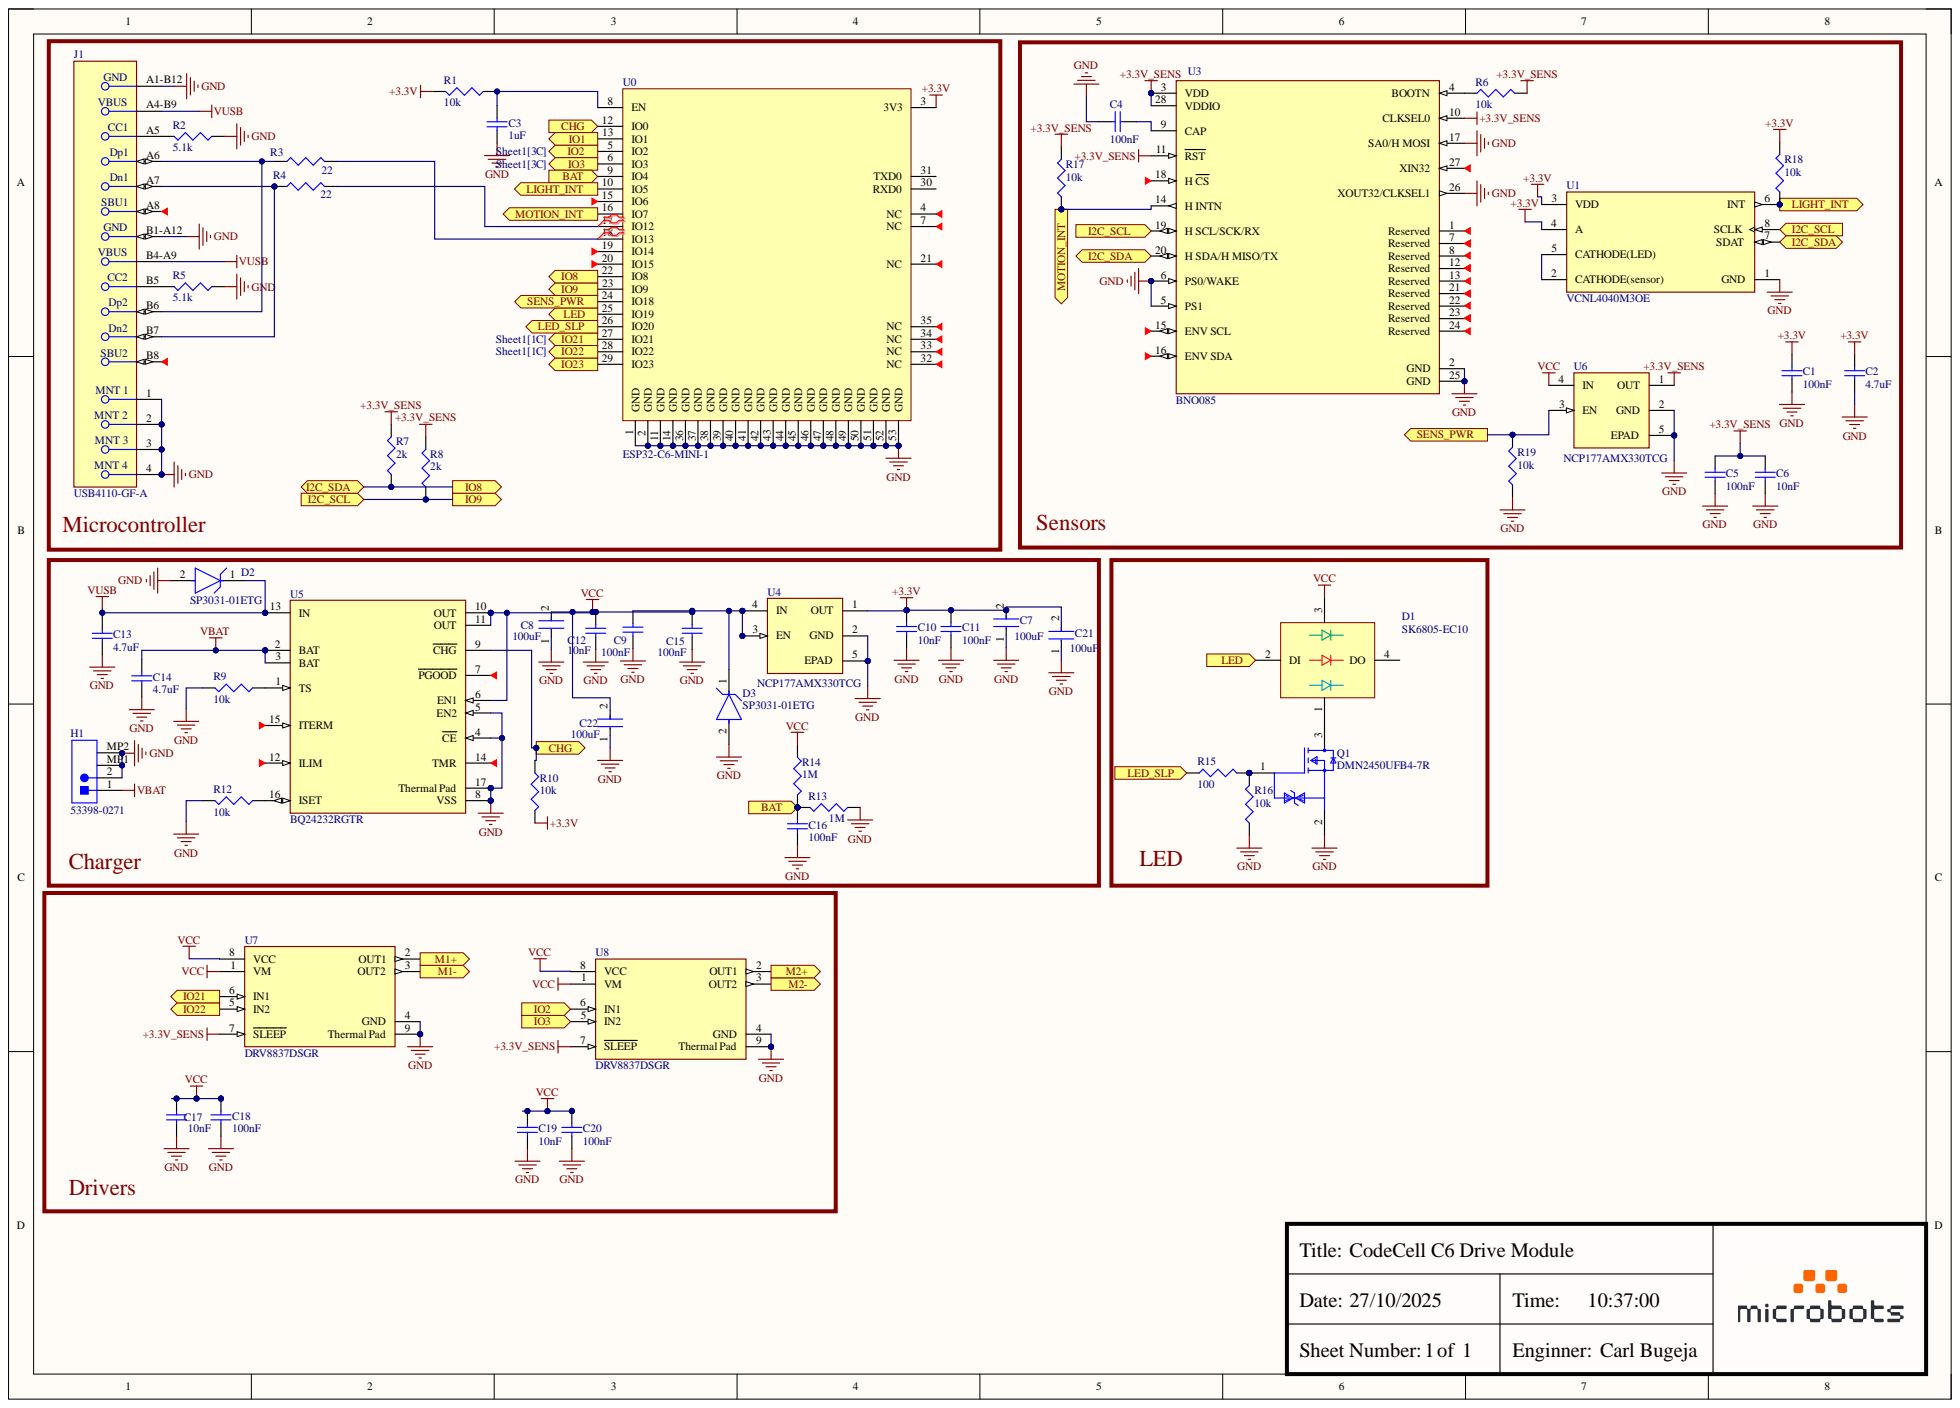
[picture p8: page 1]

Title: CodeCell C6 Drive Module

Date: 27/10/2025 | Time: 10:37:00

Sheet Number: | Enginner: Carl Bugeja

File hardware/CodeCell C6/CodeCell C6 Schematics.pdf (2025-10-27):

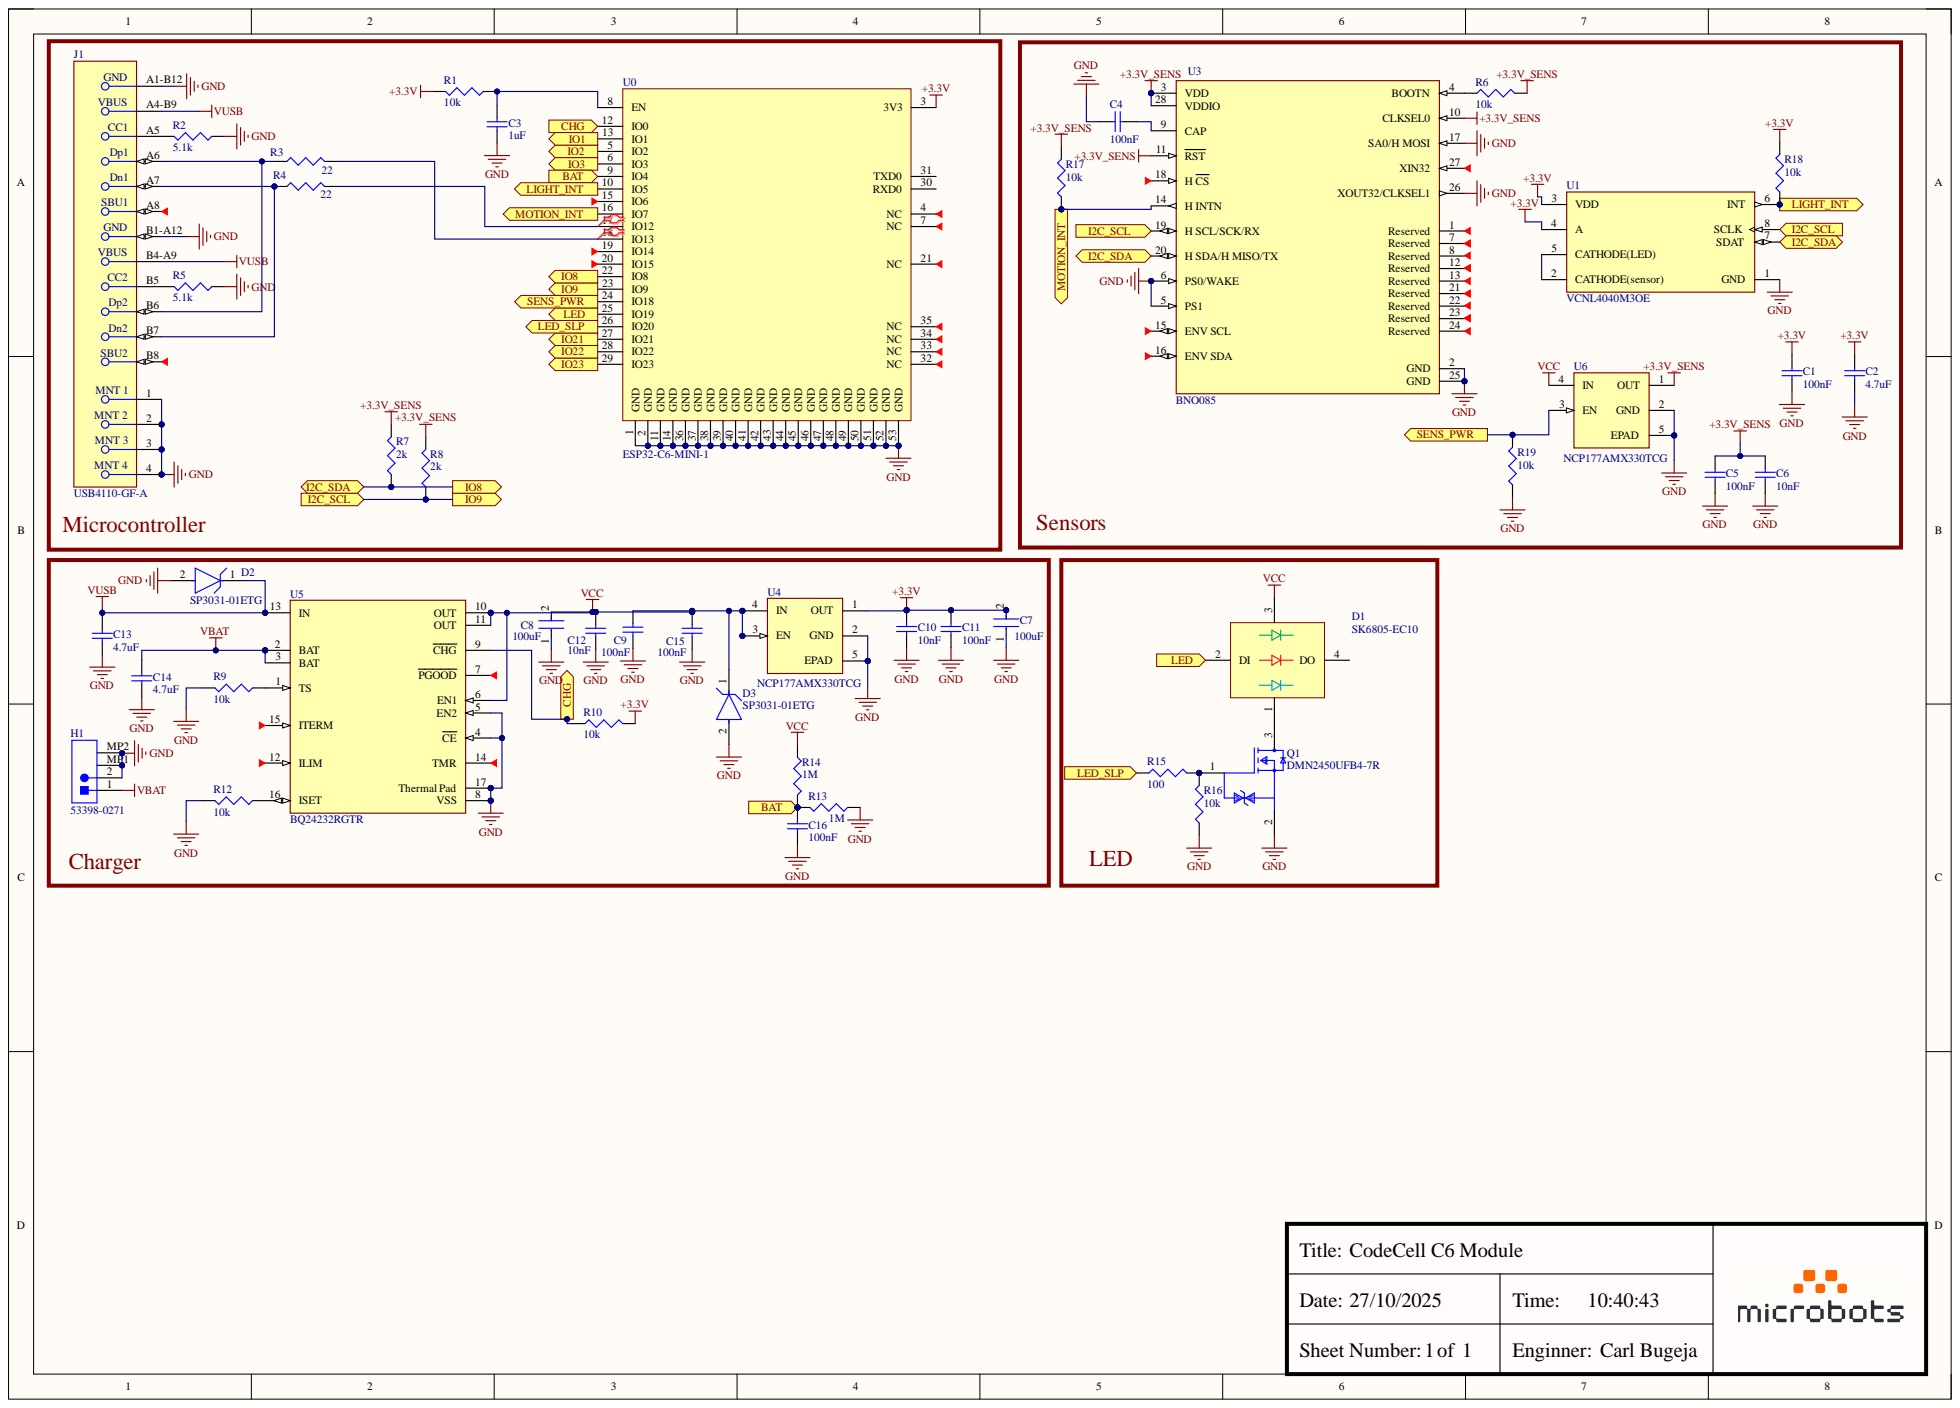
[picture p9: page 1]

Title : CodeCell C6 Module

Date : 27/10/202 51of | Time : 10:40:4 3

Sheet Number: 1 | Enginner : Carl Bugeja

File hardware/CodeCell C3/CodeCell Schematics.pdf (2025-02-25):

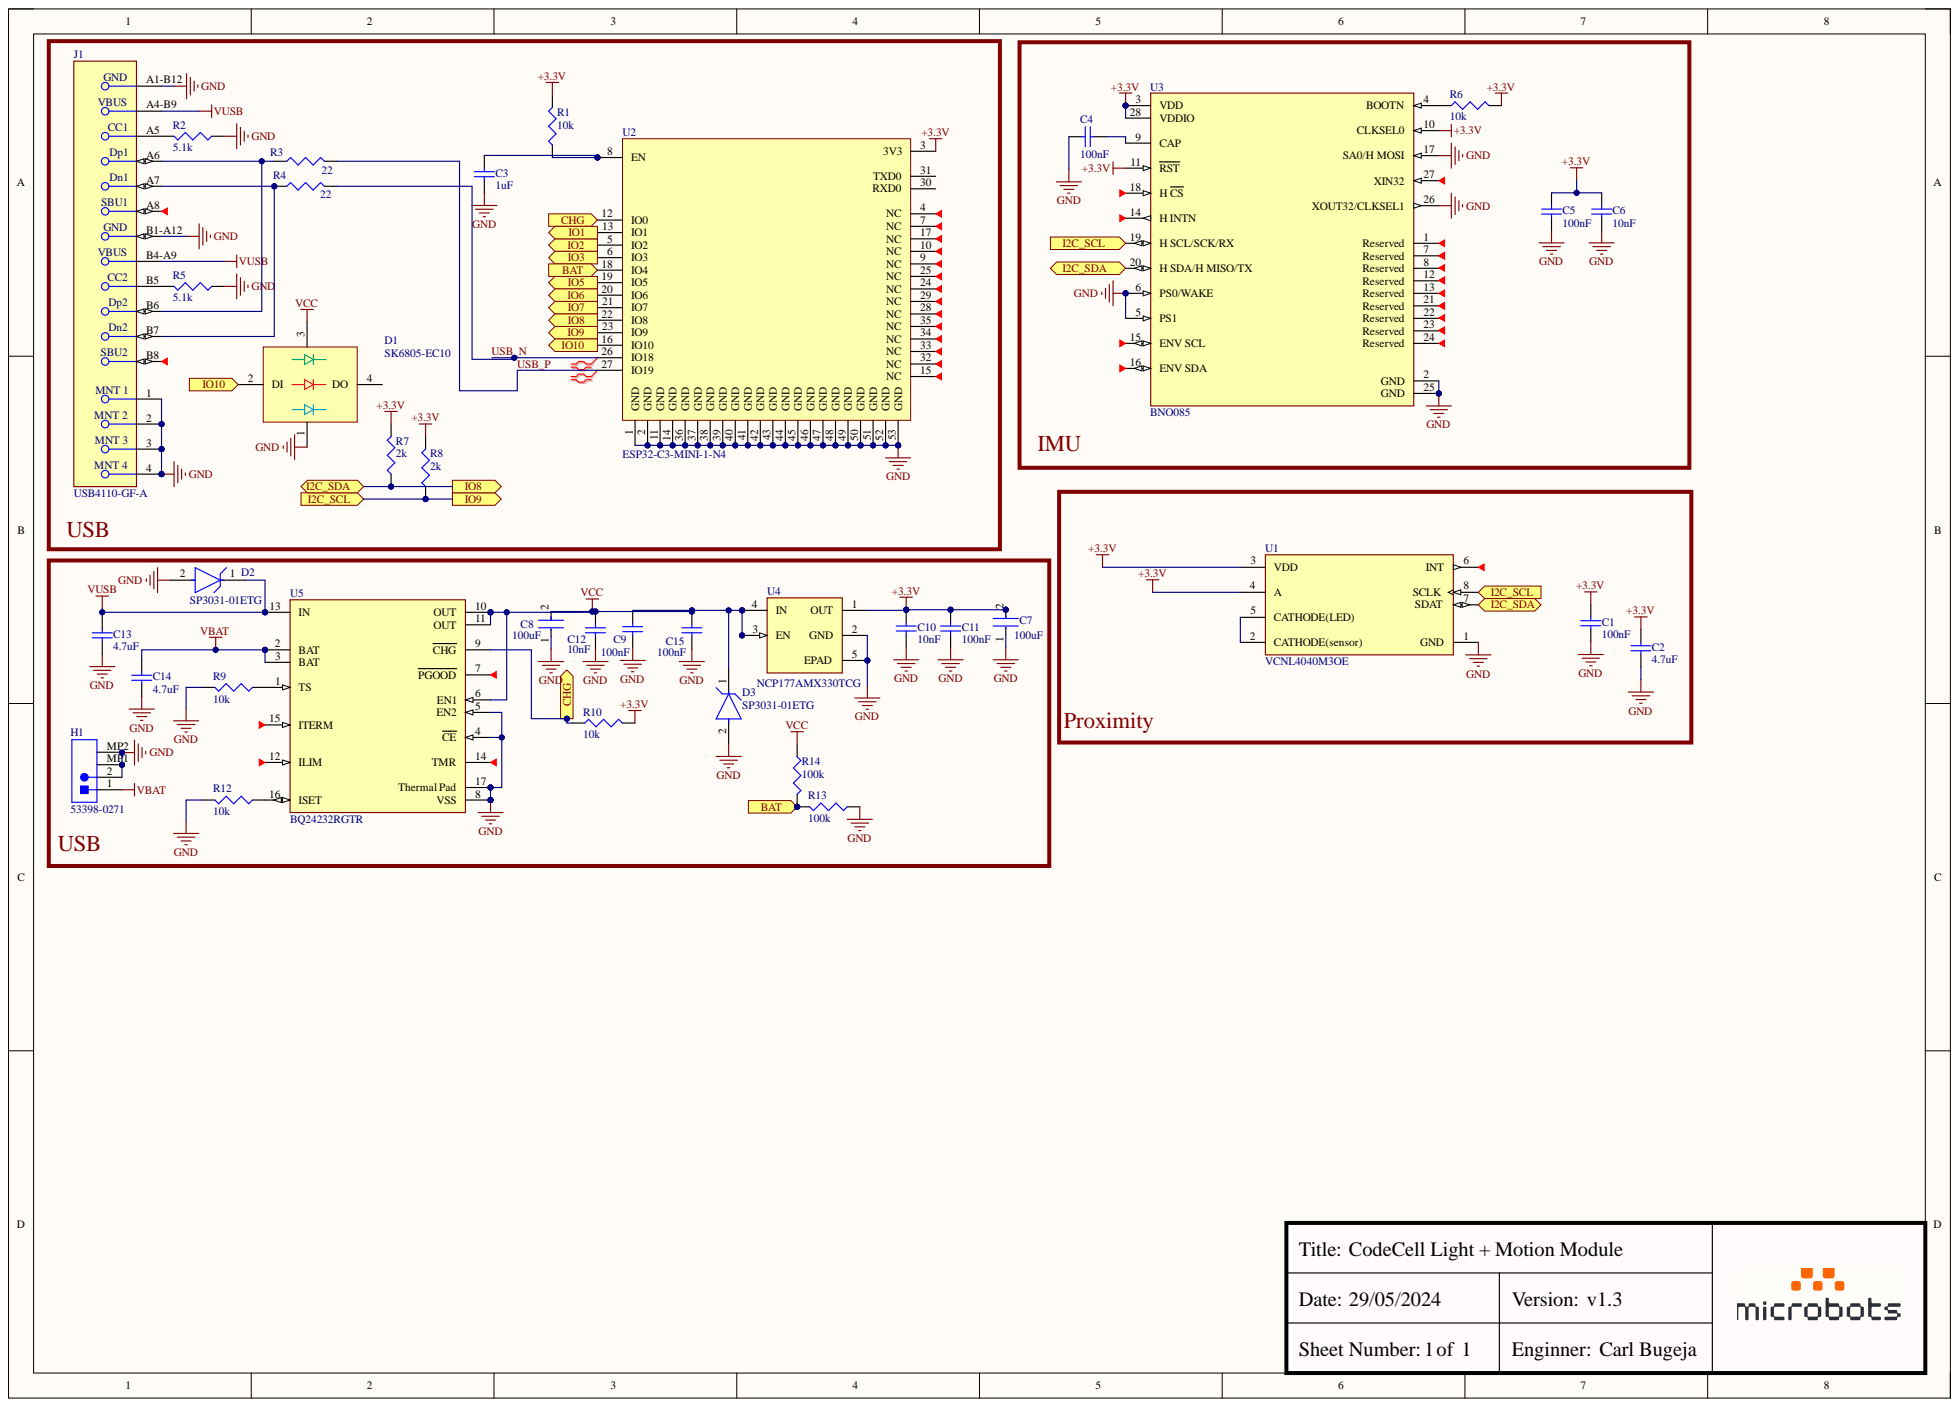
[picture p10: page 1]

Title : CodeCell Light + Motion Module

Date : 29/05/202 41of | Version : v1.3

Sheet Number: 1 | Enginner : Carl Bugeja

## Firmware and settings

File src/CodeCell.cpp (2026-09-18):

#include "CodeCell.h"
#include "BNO085.h"
#include "esp_sleep.h"

bool serial_flag = 0;
bool cc_timeflag = 1;
esp_sleep_wakeup_cause_t cc_wakeup_reason;
hw_timer_t *cctimer = NULL;

BNO085 Motion;

void IRAM_ATTR cc_Timer() {
  cc_timeflag = 1;
}

#if defined(ARDUINO_ESP32C6_DEV)
void IRAM_ATTR LightInterrupt() {
}

void IRAM_ATTR MotionInterrupt() {
}

CodeCell::CodeCell()
  : Drive2(2, 3), Drive1(22, 21) {}
#else
CodeCell::CodeCell() {}
#endif

void CodeCell::Init(uint32_t sense_motion) {
  uint8_t light_timer = 0;

#if defined(ARDUINO_ESP32C6_DEV)
  pinMode(LED_ON_PIN, OUTPUT);    /*Set LED transistor pin as output*/
  digitalWrite(LED_ON_PIN, HIGH); /*Init Set up to output high*/

  pinMode(SENS_ON_PIN, OUTPUT); /*Set LDO enable pin as output*/
  gpio_hold_dis((gpio_num_t)SENS_ON_PIN);
  digitalWrite(SENS_ON_PIN, HIGH); /*Init Set up to output high*/

  pinMode(LIGHT_WAKEUP_PIN, INPUT);   // Assumes active-low button
  pinMode(MOTION_WAKEUP_PIN, INPUT);  // Assumes active-low button
#endif

  if (WakeUpCheck()) {
    Serial.println(">> Waking up..");
    _charge_state = POWER_INIT;
    _chrg_counter = 0;
  } else {
    if (Serial) {
      delay(1500); /*Uart Setup delay*/
      serial_flag = 1;
    }
    Serial.println(" ");
    Serial.println(" ");
#if defined(ARDUINO_ESP32C6_DEV)
    Serial.print(">> CodeCell C6 v" SW_VERSION);
#else
    Serial.print(">> CodeCell C3 v" SW_VERSION);
#endif
    Serial.println(" Booting.. ");
  }

  _msense = sense_motion;

  Serial.print(">> Initializing Sensors: ");

  if ((_msense & LIGHT) == LIGHT) {
    while (Light_Init() == 1) {
      delay(10);
      LightReset();
      if (light_timer < 50U) {
        light_timer++;
      } else {
        Serial.print(" Light: Failed | ");
      }
    }
    Serial.print("Light Activated");
  }
  if ((_msense & 0b111111111111) != MOTION_DISABLE) {
    if ((_msense & LIGHT) == LIGHT) {
      Serial.print(" | ");
    }
    Motion_Init(_msense);
  } else {
    //skip
  }
  Serial.println();

  pinMode(LED_PIN, OUTPUT);   /*Set LED pin as output*/
  digitalWrite(LED_PIN, LOW); /*Init Set up to output low*/
  delay(1);
  rmtInit(LED_PIN, RMT_TX_MODE, RMT_MEM_NUM_BLOCKS_1, 10000000); /*Configure RMT to run the onboard addressable LED*/

  if (!_wakeup_flag) {
    LED(0, 0, 0);
    delay(1);
    LED(0, 0, LED_SLEEP_BRIGHTNESS);
    delay(80);
    LED(LED_SLEEP_BRIGHTNESS, 0, 0);
    delay(80);
    LED(0, LED_SLEEP_BRIGHTNESS, 0);
    delay(80);
    LED(0, 0, 0);
  }

  pinMode(0, INPUT); /*Set up Cable indication pin*/
  pinMode(4, INPUT); /*Set up Battery Voltage Read pin*/
  analogSetAttenuation(ADC_11db);


#if defined(ARDUINO_ESP32C6_DEV)
  pinMode(1, OUTPUT);
  pinMode(2, OUTPUT);
  pinMode(3, OUTPUT);
  pinMode(21, OUTPUT);
  pinMode(22, OUTPUT);
  pinMode(23, OUTPUT);
  digitalWrite(1, LOW);  /*Init Set up to output low*/
  digitalWrite(2, LOW);  /*Init Set up to output low*/
  digitalWrite(3, LOW);  /*Init Set up to output low*/
  digitalWrite(21, LOW); /*Init Set up to output low*/
  digitalWrite(22, LOW); /*Init Set up to output low*/
  digitalWrite(23, LOW); /*Init Set up to output low*/
#else
  pinMode(1, OUTPUT);
  pinMode(2, OUTPUT);
  pinMode(3, OUTPUT);
  pinMode(5, OUTPUT);
  pinMode(6, OUTPUT);
  pinMode(7, OUTPUT);
  digitalWrite(1, LOW);  /*Init Set up to output low*/
  digitalWrite(2, LOW);  /*Init Set up to output low*/
  digitalWrite(3, LOW);  /*Init Set up to output low*/
  digitalWrite(5, LOW);  /*Init Set up to output low*/
  digitalWrite(6, LOW);  /*Init Set up to output low*/
  digitalWrite(7, LOW);  /*Init Set up to output low*/
#endif

  if ((_msense & 0b111111111111) != MOTION_DISABLE) {
    Motion_Read();
    Motion_Read();
  }
  if ((_msense & LIGHT) == LIGHT) {
    Light_Read();
  }

  if (!_wakeup_flag) {
    PrintSensors();
  }
  cctimer = timerBegin(1000000);            /*Set timer frequency to 1Mhz*/
  timerAttachInterrupt(cctimer, &cc_Timer); /*Attach interrupt*/
  timerAlarm(cctimer, 100000, true, 0);     /*Set alarm to trigger every 100ms with auto-reload*/

  uint16_t battery_voltage = (((uint16_t)analogReadMilliVolts(4)) * 2U) + 65U;

  if (battery_voltage < USB_VOLTAGE) {
    _charge_color = LED_COLOR_GREEN;
  } else if (battery_voltage < MIN_BATTERY_VOLTAGE) {
    Serial.println(">> Error: Battery Volotage");
    _chrg_counter = 0;
    USBSleep();
  } else {
    _charge_color = LED_COLOR_BLUE;
  }
  for (uint8_t vv = 0; vv < AVRG_FILTER_SIZE; vv++) {
    _voltage_avrg[vv] = battery_voltage;
  }
}

void CodeCell::Test() {
#if defined(ARDUINO_ESP32C6_DEV)
  digitalWrite(1, HIGH);  /*Init Set up to output HIGH*/
  digitalWrite(2, HIGH);  /*Init Set up to output HIGH*/
  digitalWrite(3, HIGH);  /*Init Set up to output HIGH*/
  digitalWrite(21, HIGH); /*Init Set up to output HIGH*/
  digitalWrite(22, HIGH); /*Init Set up to output HIGH*/
  digitalWrite(23, HIGH); /*Init Set up to output HIGH*/
  delay(500);
  digitalWrite(1, LOW);  /*Init Set up to output low*/
  digitalWrite(2, LOW);  /*Init Set up to output low*/
  digitalWrite(3, LOW);  /*Init Set up to output low*/
  digitalWrite(21, LOW); /*Init Set up to output low*/
  digitalWrite(22, LOW); /*Init Set up to output low*/
  digitalWrite(23, LOW); /*Init Set up to output low*/
#else
  digitalWrite(1, HIGH); /*Init Set up to output HIGH*/
  digitalWrite(2, HIGH); /*Init Set up to output HIGH*/
  digitalWrite(3, HIGH); /*Init Set up to output HIGH*/
  digitalWrite(5, HIGH); /*Init Set up to output HIGH*/
  digitalWrite(6, HIGH); /*Init Set up to output HIGH*/
  digitalWrite(7, HIGH); /*Init Set up to output HIGH*/
  delay(500);
  digitalWrite(1, LOW); /*Init Set up to output low*/
  digitalWrite(2, LOW); /*Init Set up to output low*/
  digitalWrite(3, LOW); /*Init Set up to output low*/
  digitalWrite(5, LOW); /*Init Set up to output low*/
  digitalWrite(6, LOW); /*Init Set up to output low*/
  digitalWrite(7, LOW); /*Init Set up to output low*/
#endif
}

bool CodeCell::WakeUpCheck() {

  esp_sleep_wakeup_cause_t wakeup_reason;

  wakeup_reason = esp_sleep_get_wakeup_cause();
  cc_wakeup_reason = wakeup_reason;

  if ((wakeup_reason == ESP_SLEEP_WAKEUP_TIMER) || (wakeup_reason == ESP_SLEEP_WAKEUP_GPIO)) {
    _wakeup_flag = 1;
#if defined(ARDUINO_ESP32C6_DEV)
    pinMode(LED_ON_PIN, OUTPUT);     /*Set LED transistor pin as output*/
    pinMode(SENS_ON_PIN, OUTPUT);    /*Set LDO enable pin as output*/
    digitalWrite(SENS_ON_PIN, HIGH); /*Init Set up to output high*/
    delay(1);
#endif
    return true;
  } else {
    _wakeup_flag = 0;
    return false;
  }
}
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

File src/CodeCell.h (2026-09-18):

#ifndef CODECELL_H
#define CODECELL_H

#include <Arduino.h>
#include <Wire.h>

#if defined(ARDUINO_ESP32C6_DEV)
#include <DriveCell.h>
#define LED_PIN 19U
#define LED_ON_PIN 20U
#define SENS_ON_PIN 18U
#define MOTION_WAKEUP_PIN 7U
#define LIGHT_WAKEUP_PIN 5U
#else
#define LED_PIN 10U
#endif

#define SW_VERSION "2.0.8"
#define MANUFACTURER "MICROBOTS"

#ifndef CODECELL_DEBUG
#define CODECELL_DEBUG 0
#endif

#define POWER_BAT_RUN 0U
#define POWER_USB 1U
#define POWER_INIT 2U
#define POWER_BAT_LOW 3U
#define POWER_BAT_FULL 4U
#define POWER_BAT_CHRG 5U
#define USB_VOLTAGE 4220
#define MIN_BATTERY_VOLTAGE 3350

#define LED_DEFAULT_BRIGHTNESS 7U
#define LED_SLEEP_BRIGHTNESS 1U

#define LED_COLOR_RED 0XFF0000U
#define LED_COLOR_ORANGE 0XC04000U
#define LED_COLOR_YELLOW 0XA06000U
#define LED_COLOR_GREEN 0X00FF00U
#define LED_COLOR_AQUA 0X00A030U
#define LED_COLOR_PINK 0XC00020U
#define LED_COLOR_BLUE 0X0000FFU
#define LED_COLOR_WHITE 0XFFFFFFU
#define LED_OFF 0U

#define LIGHT 0b1000000000000
#define VCNL4040_ADDRESS 0x60
#define VCNL4040_ALS_CONF_REG 0x00
#define VCNL4040_ALS_THDH 0x01
#define VCNL4040_ALS_THDL 0x02
#define VCNL4040_PS_CONF1_REG 0x03
#define VCNL4040_PS_CONF3_REG 0x04
#define VCNL4040_PS_THDL 0x06
#define VCNL4040_PS_THDH 0x07
#define VCNL4040_PROX_REG 0x08
#define VCNL4040_AMBIENT_REG 0x09
#define VCNL4040_WHITE_REG 0x0A
#define VCNL4040_INT_FLAG 0x0B


#define BNO085_ADDRESS 0x4A
#define MOTION_DISABLE 0
#define MOTION_ACCELEROMETER 0b1
#define MOTION_GYRO 0b10
#define MOTION_MAGNETOMETER 0b100
#define MOTION_LINEAR_ACC 0b1000
#define MOTION_GRAVITY 0b10000
#define MOTION_ROTATION 0b100000
#define MOTION_ROTATION_NO_MAG 0b10000000
#define MOTION_STEP_COUNTER 0b100000000
#define MOTION_STATE 0b1000000000
#define MOTION_TAP_DETECTOR 0b10000000000
#define MOTION_ACTIVITY 0b100000000000


#define MOTION_STATE_UNKNOWN 0
#define MOTION_STATE_ONTABLE 1
#define MOTION_STATE_STATIONARY 2
#define MOTION_STATE_STABLE 3
#define MOTION_STATE_MOTION 4
#define MOTION_STATE_STABLE 3


#define PIN_TYPE_OUTPUT 0
#define PIN_TYPE_INPUT 1
#define PIN_TYPE_ADC 2
#define PIN_TYPE_PWM 3
#define PWM_RES 8
#define AVRG_FILTER_SIZE 8U


class CodeCell {
private:
  bool pinCheck(uint8_t pin_num, uint8_t pin_type);
  bool _pinArray[7] = { 0, 0, 0, 0, 0, 0, 0 };
  
  bool _LED_Breathing_flag = 0;
  bool _tap_event = 0;
  bool _wakeup_flag = 0;

  uint8_t _chrg_counter = 0U;
  uint8_t _lowvoltage_counter = 0;
  uint8_t _run_frequency_last = 0;
  uint8_t _power_counter = 250;
  uint8_t _charge_state = POWER_INIT;
  uint8_t _i2c_write_array[10] = { 0 };
  uint8_t _i2c_read_array[10] = { 0 };
  uint8_t _i2c_write_size = 0;
  uint8_t _voltage_index = 0;
  uint8_t _mstate_data = 0;
  uint8_t _activity_data = 0;

  uint32_t _msense = 0U;
  uint16_t _voltage_last = 0xFFU;
  uint16_t _LED_Breathing_counter = 0U;
  uint16_t _voltage_avrg[AVRG_FILTER_SIZE] = { 0 };
  uint16_t _LED_level = LED_DEFAULT_BRIGHTNESS;
  uint16_t _step_data = 0;
  uint16_t _light_data[3] = { 0 };

  uint32_t _charge_color = 0;

  float xx = 0;
  float yy = 0;
  float zz = 0;
  float _motion_data[23] = { 0.0 };

public:
#if defined(ARDUINO_ESP32C6_DEV)
  DriveCell Drive1;
  DriveCell Drive2;
#endif
  CodeCell();
  void Init(uint32_t sense_motion);
  void PrintSensors();
  void Test();
  void USBSleep();
  void SleepTimer(uint16_t sleep_sec);
  void SleepGPIOTrigger(bool STATE, uint8_t WAKEUP_PIN);
#if defined(ARDUINO_ESP32C6_DEV)
  void SleepProximityTrigger(uint16_t trigger_threshold);
  void SleepLightTrigger(uint16_t trigger_threshold);
  void SleepDarkTrigger(uint16_t trigger_threshold);
  void SleepTapTrigger();
#endif
  bool WakeUpCheck();
  bool Run(uint8_t run_frequency);
  uint16_t BatteryVoltageRead();
  uint8_t BatteryLevelRead();
  uint8_t PowerStateRead();

  void pinWrite(uint8_t pin_num, bool pin_value);
  bool pinRead(uint8_t pin_num);
  uint16_t pinADC(uint8_t pin_num);
  void pinPWM(uint8_t pin_num, uint16_t pin_freq, uint8_t pin_dutycycle);

  void LED_Breathing(uint32_t rgb_color_24bit);
  void LED(uint8_t r, uint8_t g, uint8_t b);
  void LED_SetBrightness(uint16_t level);

  bool Light_Init();
  void LightReset();
  void Light_Read();
  uint16_t Light_ProximityRead();
  uint16_t Light_WhiteRead();
  uint16_t Light_AmbientRead();

  void Motion_Init(uint32_t sense_motion);
  void Motion_EnableReports(bool print_status = true);
  void Motion_Read();
  void Motion_AccelerometerRead(float &x, float &y, float &z);
  void Motion_GyroRead(float &x, float &y, float &z);
  void Motion_MagnetometerRead(float &x, float &y, float &z);
  void Motion_GravityRead(float &x, float &y, float &z);
  void Motion_LinearAccRead(float &x, float &y, float &z);
  void Motion_RotationRead(float &roll, float &pitch, float &yaw);
  void Motion_RotationVectorRead(float &vec_r, float &vec_i, float &vec_j, float &vec_k);
  void Motion_RotationNoMagRead(float &roll, float &pitch, float &yaw);
  uint16_t Motion_StateRead();
  uint16_t Motion_ActivityRead();
  uint16_t Motion_StepCounterRead();
  bool Motion_TapDetectorRead();
};


#endif

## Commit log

2024-08-21 Update CodeCell.cpp
    Fixed uart bug
    [CodeCell.cpp]
2024-08-30 Add files via upload
    Fix related to the USB serial
    [CodeCell.cpp]
2024-09-02 Add files via upload
    Updated Init() function, SW version and fix for Motion Reset bug
    [CodeCell.cpp, CodeCell.h]
2025-01-24 Add files via upload
    v1.2.4 Updates:
    - Updated Run() Function: Now supports configurable sampling frequency between 10Hz and 100Hz.
    - Battery Management Fixes: Resolved issues related to detecting full battery charge.
    - Serial Output: Updated serial data text for better readability.
    - I2C Performance Boost: Increased I2C bus speed from 100kHz to 400kHz
    - Device Metadata: Added hardware version, device name, and manufacturer details.
    [CodeCell.cpp, CodeCell.h]
2025-02-22 Update CodeCell.cpp
    Reading Sensor in Init() function
2025-02-25 Add files via upload
    More clear schematics and updated missing values
